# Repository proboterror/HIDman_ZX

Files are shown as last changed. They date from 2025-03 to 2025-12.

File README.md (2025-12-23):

# HIDman ZX
Адаптер USB и PS/2 клавиатур/мышей для ZX Spectrum.

## Входные требования:
- Разработать универсальный простой в повторении недорогой открытый интерфейс USB / PS/2 клавиатур и мышей.
- Должны поддерживаться как минимум два USB устройства одновременно
- Включает прошивку микроконтроллера, референсную минимальную схему включения и пример тестовой платы в KiCad
- Основной фокус на сопровождаемости прошивки микроконтроллера
- Выход интерфейса клавиатуры: сигналы матрицы переключателей A8-A15, D0-D4
- Выход интерфейсов Kempston Mouse и Kempston Joystick: сигналы DI0-DI7, стробы записи регистров MX, MY, MKEY, JOY

**Дополнительно:**
- Поддержка USB HID геймпадов как Kempston Joystick и для эмуляции кнопок клавиатуры
- Выход сигналов для управления кнопками эмулятора дисковода GOTEK по горячим кнопкам клавиатуры
- Выход сигналов управления Z80 по горячим кнопкам клавиатуры: BUSRQ (PAUSE), NMI(MAGIC), RESET

**Не входит в требования:**
- Реализация платы для ZX-BUS
- Реализация портов и регистров контроллеров ZX клавиатуры и Kempston Mouse
- Реализация защиты портов USB от статики / короткого замыкания / повышенного напряжения

## Реализация
В качестве основы проекта был взят проект [HIDman](https://github.com/rasteri/HIDman): USB HID to XT / AT / PS/2 / Serial converter : адаптер USB устройств в PS/2 keyboard/mouse device. От HIDman была взята реализация стека USB Host без модификаций.

Схема использует недорогие доступные чипы от [Nanjing Qinheng Microelectronics](https://www.wch-ic.com):
- 8-bit Enhanced USB MCU [CH559L](./doc/8-bit%20Enhanced%20USB%20MCU%20CH559%20Datasheet%201.6.pdf): расширенный Intel 8051 совместимый микроконтроллер с двумя аппаратными USB Host
- 8x16 Analog Switch Array Chip [CH446Q](./doc/8x16%20Analog%20Switch%20Array%20Chip%20CH446Q%20Datasheet%201D.pdf): матрица аналоговых ключей 8x16 с последовательным интерфейсом

В код добавлены:
- Реализация асинхронных интерфейсов PS/2 клавиатуры и мыши
- Реализация матрицы контактов 8x5 ZX Spectrum клавиатуры с раскладкой Xrust
- Интерфейс матрицы ключей CH446Q
- Интерфейс для контроллера Kempston Mouse (DI+MX/MY/MKEY)
- Интерфейс для контроллера Kempston Joystick (DI+JOY)
- Интерфейс управления Z80 (PAUSE/MAGIC/RESET) по клавишам F10/F11/F12
- Интерфейс управления кнопками GOTEK (RIGHT/LEFT/SELCT) по сочетанию клавиш CTRL+ RIGHT/LEFT/DOWN/UP

## Детали реализации

Тестовая плата для отладки присоединяется сверху к [ZX Spectrum Pentagon 128 2023/2024 Interface Board](https://github.com/proboterror/Pentagon_128_Interface_Board). Исходя из этого выбраны физические размеры и положение / распиновка разъема клавиатуры.

Интерфейс мыши расчитан на подсоединение к контроллеру, подобному [ZX_BUS_Mouse](https://github.com/proboterror/ZX_BUS_Mouse) с параллельной записью по шине 8-bit в регистры осей и колеса/кнопок. Колесо прокрутки мыши поддержано.

Исходный код поддержки PS/2 клавиатуры и интерфейса матрицы ZX Spectrum => CH446Q портирован из проекта расширенного интерфейса [ZX_RGBI2VGA-HDMI + GOTEK FlashFloppy I2C OSD + PS/2 Keyboard](https://github.com/proboterror/zx-rgbi-to-vga-hdmi_gotek-osd)

Исходный код поддержки PS/2 мыши портирован из экспериментальной ветки interrupt_processing_async проекта [ZX BUS Mouse](https://github.com/proboterror/ZX_BUS_Mouse/tree/interrupt_processing_async). Код обработки мыши по прерыванию clock в свою очередь основан на проекте Олега Трифонова [avr-mouse-ps2-to-serial](https://github.com/trol73/avr-mouse-ps2-to-serial). Код инициализации PS/2 мыши и основной цикл обработки событий асинхронный с минимальными задержками.

Тестирование показало, что MCU CH559L может работать от внутреннего генератора без использования внешнего кварцевого резонатора, выбор источника частоты из кода инициализации PLL.<br>
Конденсатор и резистор цепочки сброса MCU CH559L не нужны, т.к. есть внутренняя схема формирования сброса по питанию.

При тестировании проявился дефект: после подачи питания Gluk Reset Service всегда выводит экран Help, после нажатия Reset Z80 стартует нормально. Зажата клавиша 'A' ZX клавиатуры (адрес переключателя в матрице CH449Q 0x01) до момента программного зануления всех переключателей в CH449Q.<br>
В варианте с MCU RP2040 дефект не проявлялся.<br>
Расследование показало, что RP2040 при включении переводит (большинство) GPIO в режим input c pull-down (подтяжка к земле), выдавая логический '0' на GPIO pin. MCU CH559 при подаче питания активирует для портов pull-up резисторы (подтяжка к питанию 3.3V), выдавая логический '1' на выходы. Матрица переключателей CH446Q записывает значение сигнала DAT по адресу ранее выбранного переключателя при высоком уровне сигнала STB. Так как после аппаратного сброса CH446Q на входах STB и DAT был логический '1', то это приводило к нежелательной активации переключателя по адресу 0x01 (видимо в это значение сбрасывается внутренний регистр адреса).<br>
После подтяжки линии STB внешним резистором 10K к GND проблема почти решилась, но оставался нежелательный импульс длительностью 0.5 us в момент инициализации портов MCU. CH559 при сбросе инициализирует регистры P0..P3 выходного значения портов в значение 1111 1111b, и выстановка регистра P1 в 0x00 сразу после переключения порта P1 на выход приводила к такому эффекту. Исправлено выстановкой значения порта P1 до переключения его на выход.

## Режимы работы выходов
Входы / выходы матрицы клавиатуры A8-A15, D0-D4 и управляющих сигналов Z80 BUSRQ, NMI, RESET подключены к входам / выходам матрицы аналоговых ключей CH446Q. Общий вход X8 для сигналов Z80 BUSRQ, NMI, RESET подключен к GND.

Выходы кнопок GOTEK работают в режиме с открытым коллектором, при нажатии замыкают на GND.

Выход интерфейса Kempston Mouse и Kempston Joystick работает в режиме push-pull.

## Схема
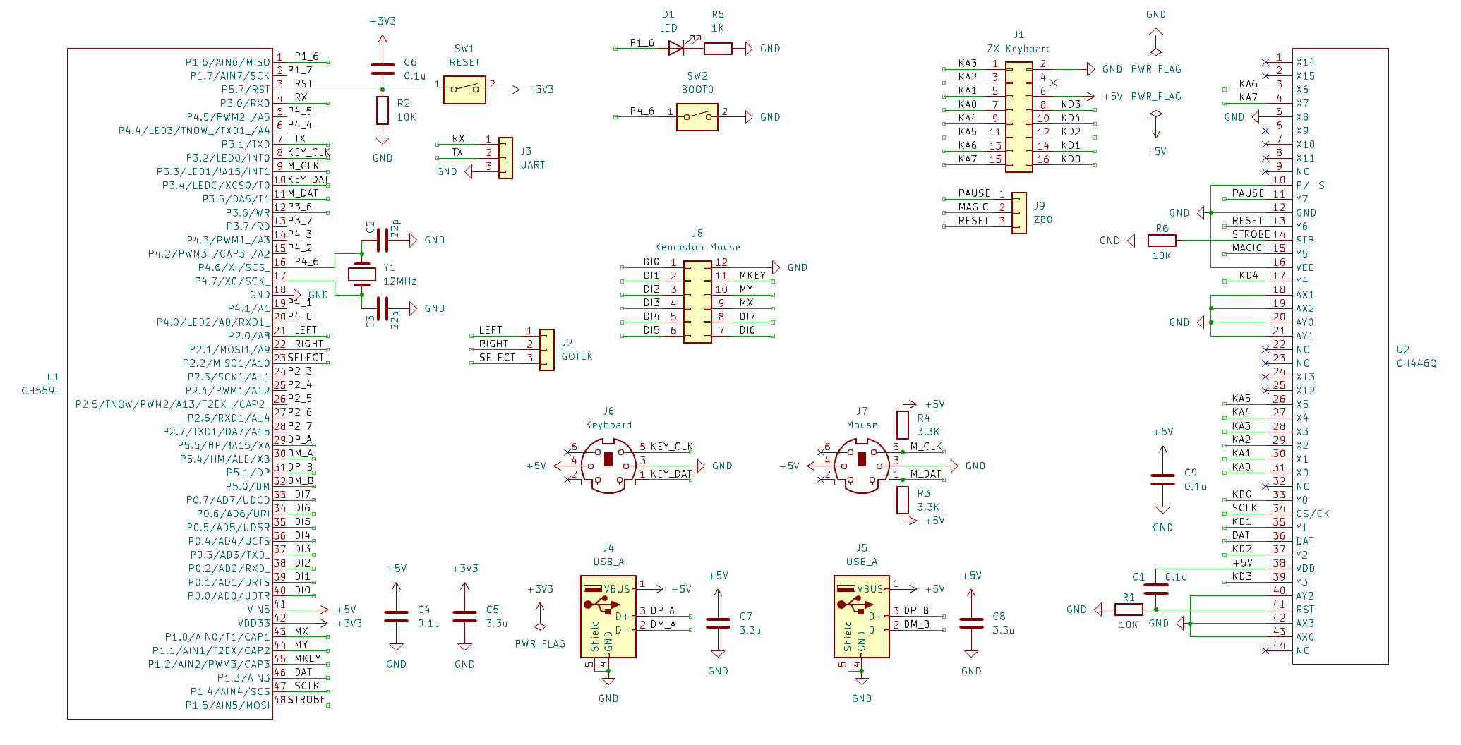
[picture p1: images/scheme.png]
scheme

## Тестовая плата
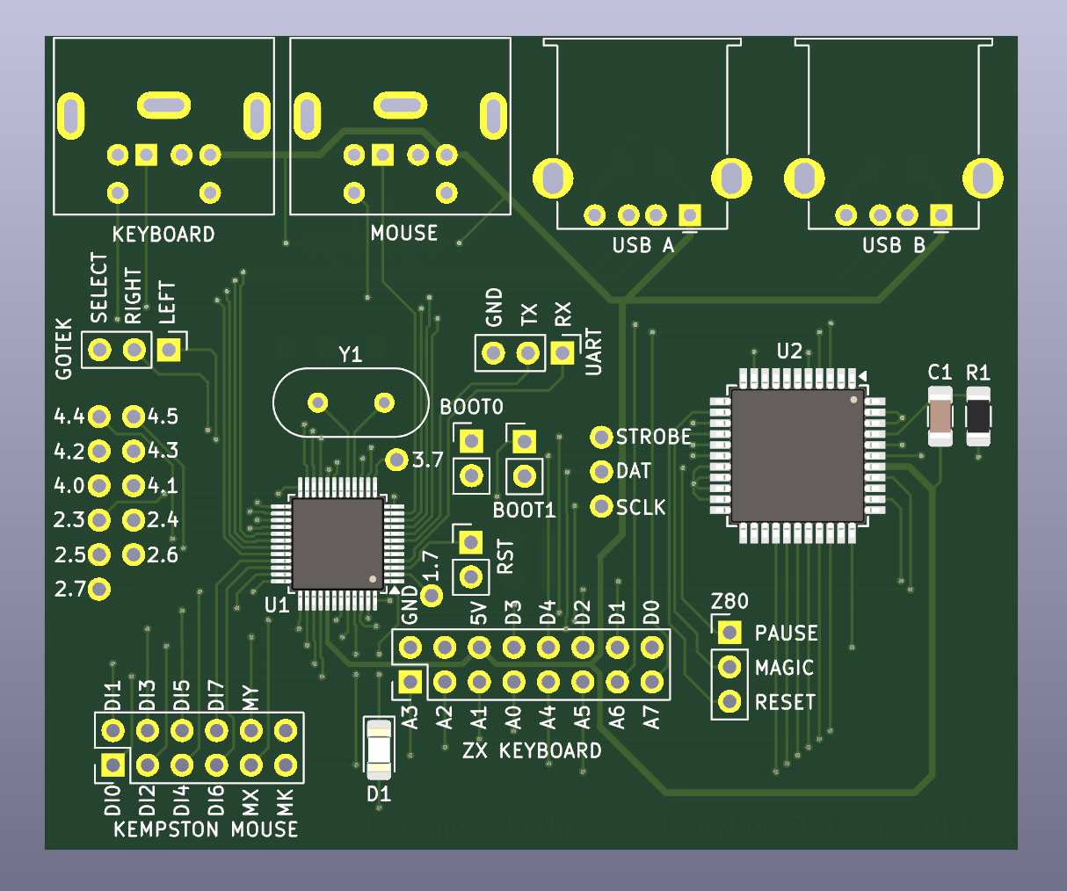
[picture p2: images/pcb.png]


## Текущий статус
- В firmware реализована поддержка PS/2 и USB мышей и клавиатур.
- Поддерживаются беспроводные мыши / клавиатуры Logitech c Unified Receiver и им подобные, работающие как стандартный USB HID.
- Реализована поддержка геймпадов/джойстиков, совместимых с USB HID, в том числе Sony DualShock 4, Sony PlayStation 5 DualSense.
- Реализованы специальные драйверы для геймпадов Sony DualShock 3, XBox 360 USB Controller, XBox One / Series S/X Controller.
- Реализована экспериментальная поддержка SEGA Mega Drive / Genesis геймпада как 3-кнопочного.
- Проверена работа выходных портов мыши / клавиатуры / джойстика / GOTEK / Z80.
- Поддержка USB хабов и конфигурация беспроводная клавиатура/мышь + gamepad не тестировались, но заявлены в оригинальном проекте.
- События от USB HID геймпадов транслируются в нажатия кнопок клавиатуры и Kempston Joystick.
- События от геймпадов с специальным драйвером транслируются в нажатия Kempston Joystick.

## Известные проблемы

## ToDo
- Код обработки событий от PS/2 клавиатуры не обрабатывает ошибки parity. После тестирования стабильности работы уточнить необходимость отправки устройству PS/2 команды RESEND / RESET и очистки буфера ввода.
- Добавить минимальный код трансляции нажатия кнопок геймпадов с специальным драйвером (PS3/XBox) в события клавиатуры.
<hr>

# Вариант для шины ZX-BUS (Nemo-BUS)
Для большей осмысленности существования прошивки MCU и востребованности реализована плата в формате ZX-BUS с полной поддержкой всех возможностей прошивки.

Плата реализует интерфейсы клавиатуры, Kempston Mouse и Kempston Joystick (8 bit), позволяет подключить как минимум 2 USB устройства и PS/2 клавиатуру / мышь.<br>
Интерфейс клавиатуры работает одновременно с портом клавиатуры / магнитофона на основной плате компьютера.

## Схема
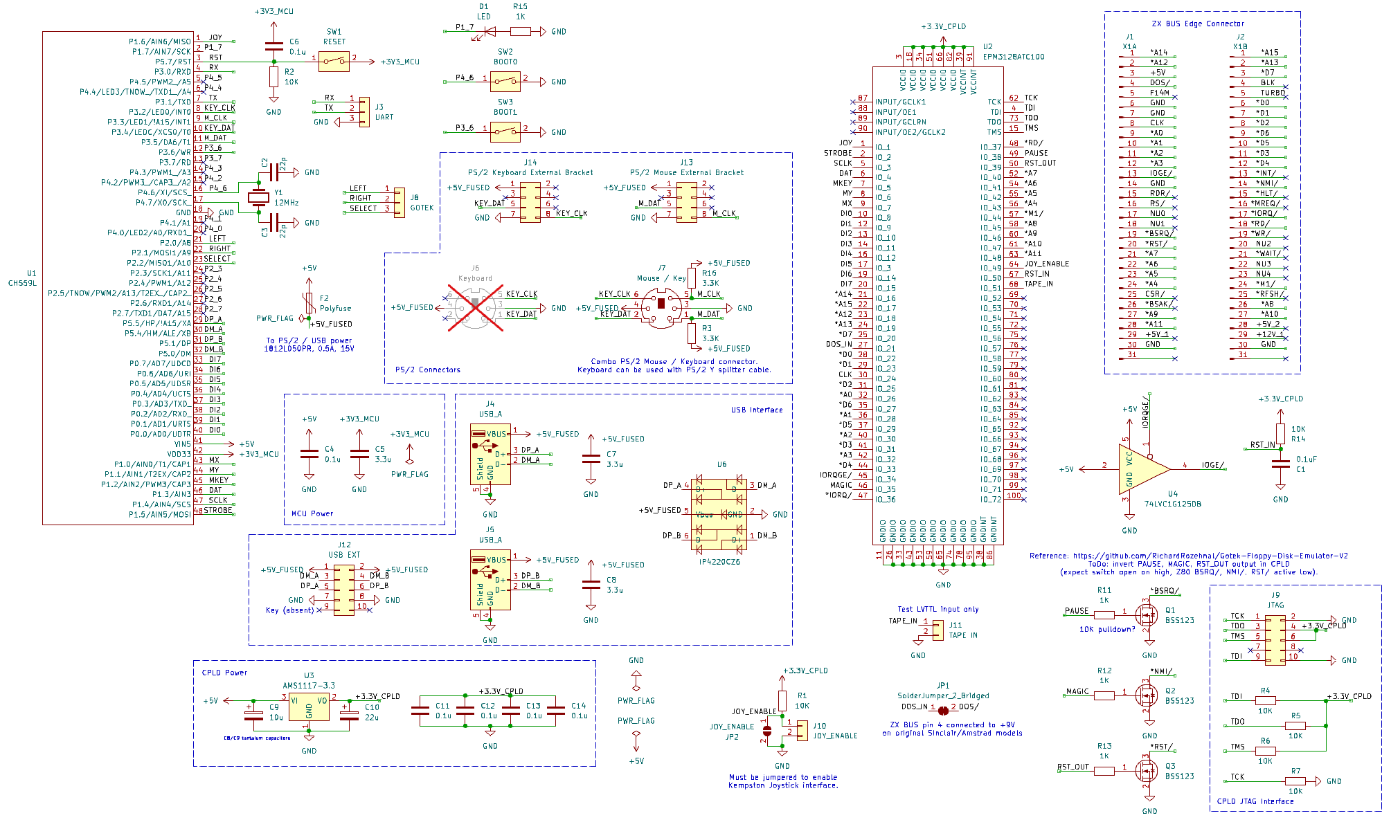
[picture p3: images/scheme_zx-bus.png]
scheme

## Плата
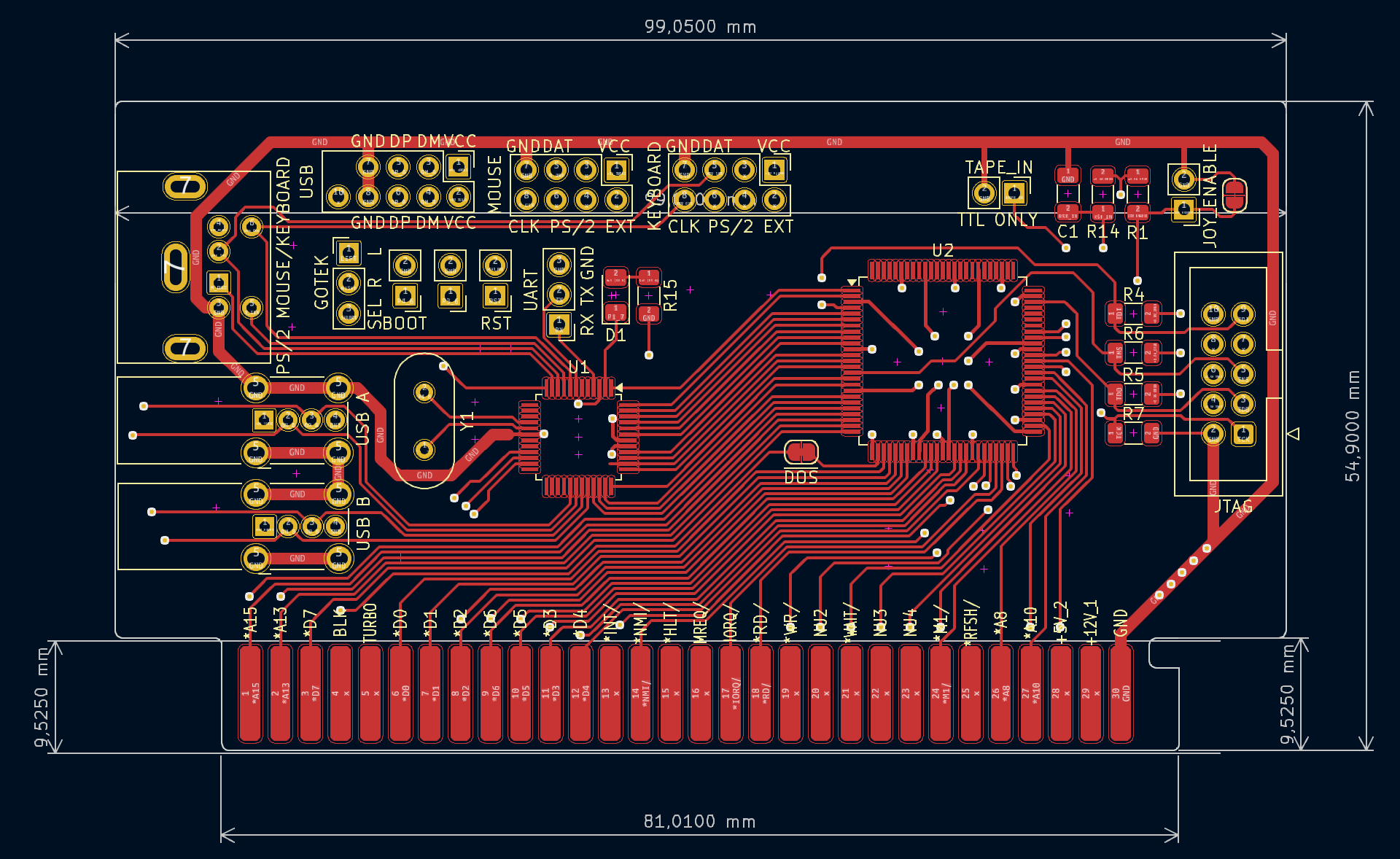
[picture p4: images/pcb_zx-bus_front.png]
front

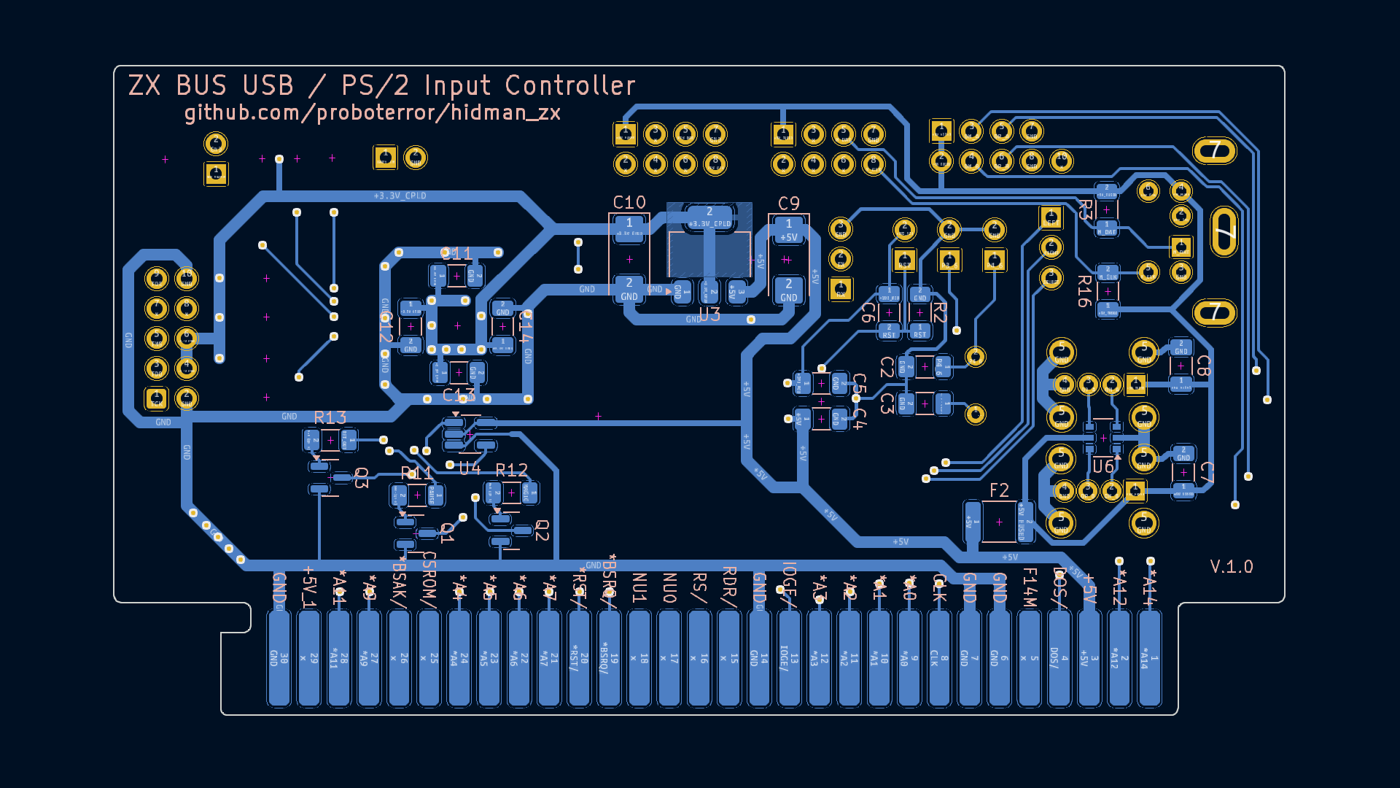
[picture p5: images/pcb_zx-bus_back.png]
back

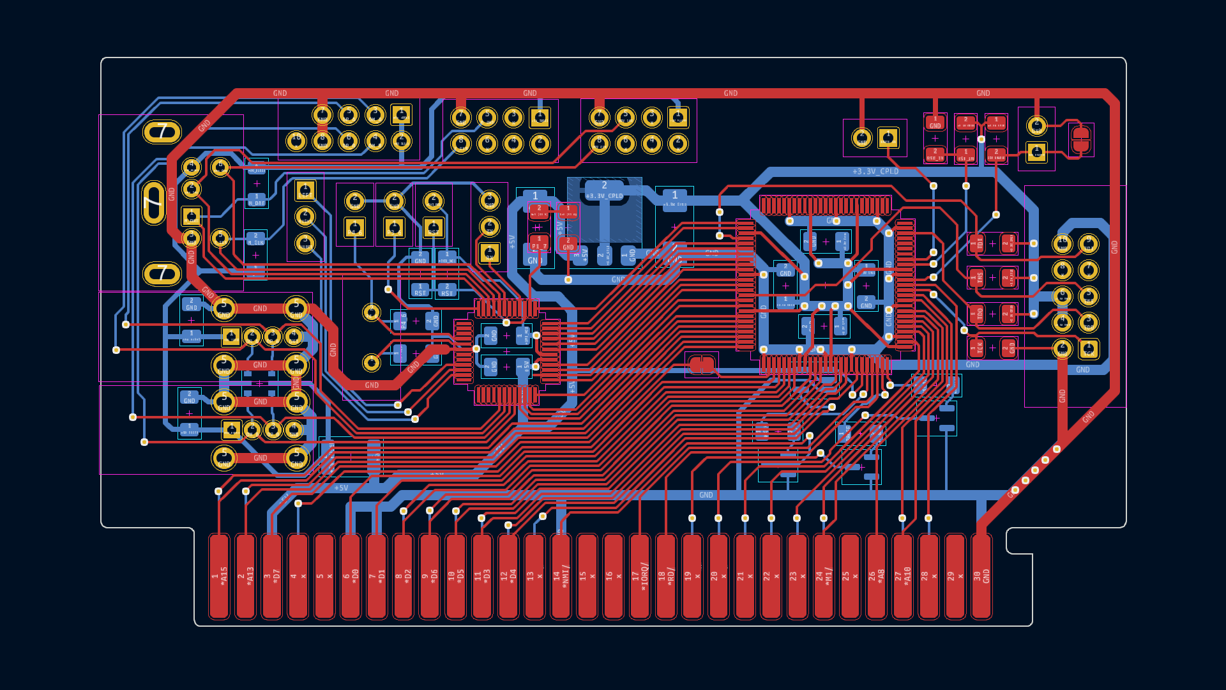
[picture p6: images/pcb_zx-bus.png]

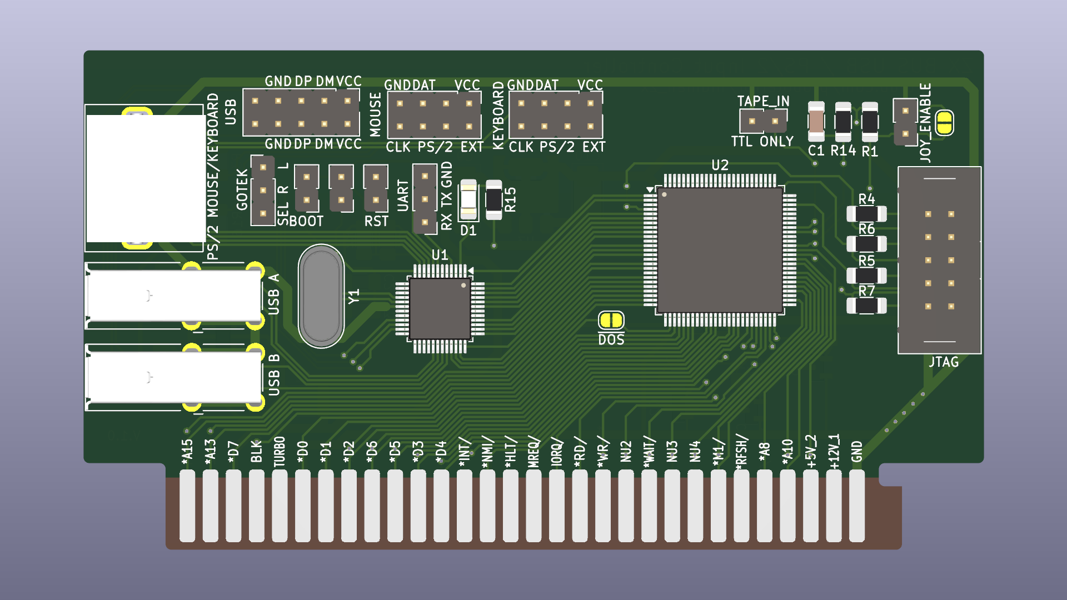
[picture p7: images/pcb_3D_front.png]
3D front

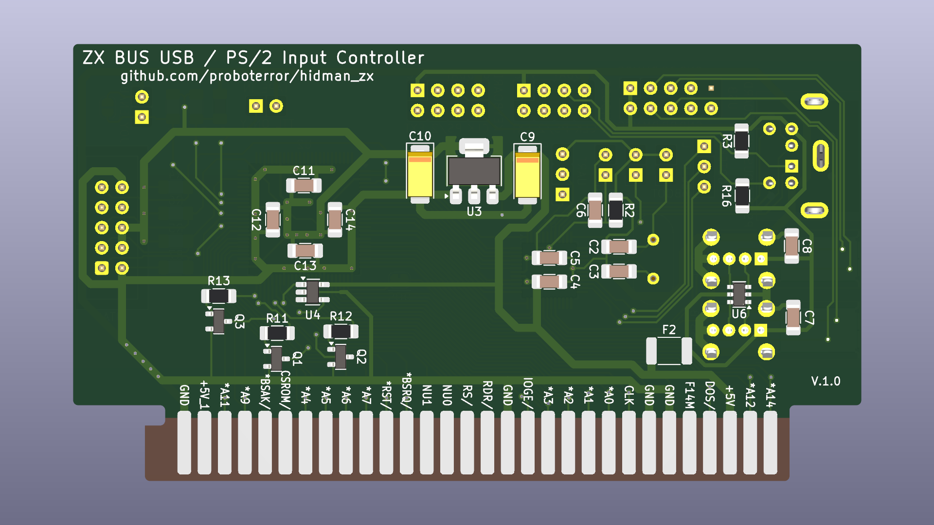
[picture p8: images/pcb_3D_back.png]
3D back

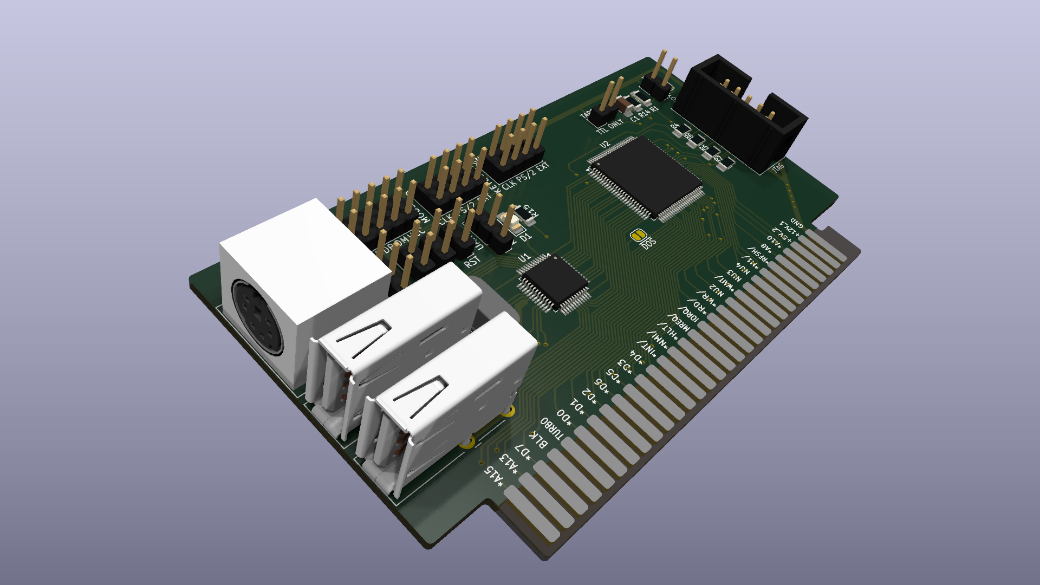
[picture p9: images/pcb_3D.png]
3D


## Выбор требований
- Плата должна содержать 2 порта USB и порты PS/2 мыши / клавиатуры, с возможностью подключения стандартных внешних планок.
- Использовать доступные и недорогие компоненты.
- Высота платы должна быть минимально возможной, максимальна ширина / высота 99 мм.
- Предусмотреть защиту портов от короткого замыкания (PS/2 / USB) и статического электричества (USB). Плата должна быть работоспособна без запаянных элементов защиты портов USB от статического электричества.
- Порт Kempston Joystick должен быть отключаемый по причине потенциальных конфликтов / не нужности.
- Штыревые разъемы не обязательны к запайке.
- SMD конденсаторы и резисторы форм фактора 1206 для удобства ручной сборки.

## Детали реализации
Матрица переключателей клавиатуры и специальных кнопок вместо отдельного чипа CH446Q помещена в CPLD вместе с дешифраторам адресов и регистрами интерфейсов, с сохранением последовательного интерфейса для доступа (drop-in replacement).

CPLD Altera EPM3128ATC100 выбрана исходя из доступности и минимальной необходимой емкости в макроячейках.<br>

Текущая реализация использует неполную дешифрацию портов клавиатуры, Kempston Mouse, Kempston Joystick.<br>
В идеале для Kempston Joystick желательна полная дешифрация нижних 8 бит адреса порта #1F, но для этого нужна нетривиальная оптимизация.<br>

Плата не блокирует встроенные порты клавиатуры и магнитофона для их параллельной работы.<br>
Плата полностью блокирует встроенный порт Kempston Joystick и порты Kempston Mouse; можно отредактировать описание для параллельной работы интерфейсов Kempston Joystick.<br>
Интерфейс клавиатуры для разделения шины данных подключается к шине в режиме с открытым коллектором.

Использовано порядка 107 из 128 макроячеек. Сложность описания и потребление элементарных компонентов (AND, OR, MUX, tri-state) в выходной RTL map требует особого внимания, при увеличении сложности fitter не может распределить ресурсы CPLD.<br>
Описание схемы в CPLD и testbench для тестирования написаны на языке System Verilog.

Интерфейс Kempston Joystick восьмибитный (4 направления + 4 кнопки) и по умолчанию отключен, включение через jumper / solder jumper.

Интерфейс мыши полный с поддержкой колеса мыши и трех кнопок.

Сигнал IORQGE/ буферизирован до уровня 5V через tri-state буфер 74LVC1G125DB.<br>
Сигналы PAUSE, MAGIC, RESET от CPLD буферизированы на сигналы шины Z80 BUSRQ/, NMI/, RST через FET транзисторные ключи BSS123.

Набор и форма разъемов выбраны исходя из минимальной высоты платы и потенциальной востребованности.<br>
По этой причине разъем PS/2 mini DIN 6 pin комбинированный: PS/2 мышь может быть подключена напрямую, для подключения PS/2 клавиатуры потребуется доступный недорогой Y splitter cable.

Разъемы USB компактные вертикальные [Würth Elektronik 614004134726](https://www.we-online.com/en/components/products/COM_TYPE_A_UP_RIGHT#614004134726) или их распространенные [аналоги](https://aliexpress.ru/item/1005003752018041.html?sku_id=12000028387034115).

Сигналы обоих портов USB и PS/2 мыши / клавиатуры также выведены на штыревые разъемы для подключения стандартных внешних планок/выбросов для двух портов USB или отдельных портов PS/2.

## Схема сброса CPLD
Важный момент, в многих реализациях игнорируемый.<br>
Для корректной работы ПО в ROM, исполняемого сразу после _включения_ компьютера, например Gluk Reset Service, требуется чтобы регистры матрицы клавиатуры и контроллера Kempston Mouse содержали корректные значения почти сразу после включения (порядка 24 ms): микроконтроллер интерфейса не успевает обновить их значения.<br>
Необходим внутрисхемный сброс регистров CPLD в нужное состояние по системному сигналу RESET _или_ самостоятельное формирование сигнала сброса при включении.<br>
Выбран второй вариант, т.к. CPLD также может формировать системный сигнал RESET (RST_OUT) исходя из значения внутреннего регистра, и это может вводить циклическую зависимость.

Сброс происходит по нисходящему фронту сигнала (более правильно было бы по уровню сигнала).

## Защита портов
Защита портов USB / PS/2 от короткого замыкания: самовосстанавливающийся предохранитель форм-фактора 1812 (Littelfuse 1812L050PR, 0.5A, 15V) (номинал требует уточнения, предельная нагрузка отдельного порта USB 0.5A@5V, возможно заменить на Bourns MF-NSMF075-2, 0.75 А, 6V, 1206).

Защита портов USB от статического электричества: [IP4220CZ6 Dual USB 2.0 ESD Protection TVS Array](doc/IP4220CZ6%20Dual%20USB%202.0%20integrated%20ESD%20protection%20[NXP].pdf). Может быть не установлена.<br>
В плате версии 1.0 подключена некорректно (?) и не должна устанавливаться.<br>
В плате версии 1.1 подключена в соответствии с datasheet, но блокирует порт USB для прошивки MCU.

## Зарезервированные сигналы
В CPLD заведены, но не используются сигналы шины ZX-BUS: CLK.<br>
Также заведен сигнал DOS/. Сигнал присутствует только на шине Nemo-BUS xUSSR клонов, в оригинальных моделях ZX-Spectrum с шиной ZX-BUS на этом контакте напряжение питания +9V. Чтобы обратить внимание на этот момент, сигнал подключен через замкнутый solder jumper.

## Порт Tape In
Порт входа магнитофона подключен к 6 биту порта #FE клавиатуры, соответственно при блокировке внутреннего порта клавитуры потенциально отключается и порт магнитофона.<br>
Для экспериментов на плате выведен разъем TAPE_IN. К порту можно подключить только LVTTL 3.3V сигнал, например от эмулятора магнитофона на TZXDuino.

## Текущий статус
- Прошивка CPLD проверена через testbench в ModelSim: опция "Tools/Run EDA Simulation Tool/EDA RTL Simulation" в Quartus. Должен быть установлен ModelSim из дистрибутива Quartus (использовалась версия 13.0sp1).
- Платы собраны и протестированы.
- Протестированы контроллеры Kempston Mouse, Kempston Joystick, ZX матричной клавиатуры: работают, корректно сбрасываются при включении. Реализация матрицы клавиатуры позволяет зажимать много кнопок без эффекта фантомных нажатий, в том числе при маппинге с HID геймпада.
- Клавиатура работает параллельно с портом клавиатуры и магнитофона на основной плате.
- Работа сигналов PAUSE, MAGIC, RESET через транзисторные ключи на шину проверена.
- Работа TTL входа TAPE_IN не проверена.
- ESD защита портов блокирует работу USB и не должна устанавливаться.

## Известные проблемы
- При включении в прошивке CPLD поддержки всех трех интерфейсов (Mouse, Joystick, Keyboard) (107 из 128 macrocells) интерфейс клавиатуры начинает работать нестабильно, в том числе при нажатии определенной кнопки джойстика.
Предположительно связано с неоптимальным распространением сигналов в комбинаторной схеме при большом заполнении CPLD.
В качестве временного решения закомментирована поддержка Kempston Joystick (94 из 128 macrocells).

## Сборка проекта
Для сборки прошивки из исходников потребуются: компилятор SDCC 3.9.3, GNU утилиты в составе msys2.
- Скопировать / установить [SDCC 3.9.3](https://github.com/atc1441/CH559sdccUSBHost/tree/master/SDCC). Добавить путь к SDCC/bin в переменную окружения PATH.
- Установить [MSYS2](https://www.msys2.org/). Путь к msys64/usr/bin должен быть в PATH.

Компиляция:
```
cd firmware
build-release.bat
```
Файлы прошивки сохраняются в каталоге firmware/out

## Прошивка CH559L
Необходимо установить [WCH ISP Studio](https://www.wch.cn/downloads/WCHISPTool_Setup_exe.html)
См. оригинальную инструкцию по прошивке ниже.

Потребуется кабель USB A - USB A (вилка - вилка).

Вход в режим програмирования:
- Запустить WCH ISP Studio, выбрать режим 
- Отсоединить контроллер от внешнего питания / устройств
- Замкнуть jumper BOOT0 (P4.6)
- Подключить контроллер через разъем USB_B к ПК
- Контроллер должен появиться в списке Dev list
- При неудаче повторить

Программирование:
- Выбрать файл прошивки
- Нажать Download
- При неудаче повторить

Примечания:
- Процедура прошивки может быть нестабильной / очень нестабильной в зависимости от контроллера USB в ПК.
- Вход в режим программирования через запуск bootloader'а прошивкой при сбросе (BOOT1 + RESET) не тестировался.
- Для CH559L заявлена поддержка serial programmer, есть опция в WCH ISP Studio и доступен инструмент [CH55x_python_flasher](https://github.com/hexeguitar/CH55x_python_flasher) для Windows / Linux, не тестировалось.

## Схожие проекты
[Контроллер для USB клавиатуры и мыши](https://zx-pk.ru/threads/34912-kontroller-dlya-usb-klaviatury-i-myshi.html)
[[github]](https://github.com/Igor-azx987sa/ZXKM)<br>
(С) Игорь Матвеев @azx987sa 2023<br>
Микроконтроллер ATmega328P, USB HOST controller CH9350, EPM7128<br>

[PentagonExpander](https://github.com/MikhaelKaa/pentagonexpander) (WiP)<br>
(С) Михаил Каа MikhaelKaa 2023<br>
USB / PS/2 мышь / клавиатура, Kempston Mouse / Joystick для Pentagon 128<br>
Микроконтроллер STM32, CPLD EPM7128

[USB2SPECTRUM](https://github.com/MikhaelKaa/usb2spectrum) (WiP)<br>
(С) Михаил Каа MikhaelKaa 2023-2024<br>
USB клавиатура / gamepad, PS/2 клавиатура, Kempston Joystick.<br>
Микроконтроллер STM32, CPLD EPM7064

[Периферийный контроллер для Скорпиона с поддержкой USB](https://zx-pk.ru/threads/34458-periferijnyj-kontroller-dlya-skorpiona-s-podderzhkoj-usb.html)
[[github]](https://github.com/psk7/scorpion-card-pub)<br>
(С) Kireev Sergey psk 2022<br>
Микроконтроллер ATmega328P, USB HOST controller MAX3421EEHJ, EPM3064

[usb_to_zx_spectrum](https://github.com/billgilbert7000/usb_to_zx_spectrum)<br>
(C) Constantin billgilbert7000 2024<br>
Универсальный контроллер USB клавиатуры для подключения к компьютерам ZX Spectrum.<br>
Микроконтроллер RP2040, матрица ключей MT8816

[ZX HID Keyboard Controller](https://zx-pk.ru/threads/24088-zx-hid-keyboard-controller.html)<br>
(C) Anykey 2014<br>
Микроконтроллер PIC24FJ64GB002, EPM7064

[PS/2 Universal Keyboard Controller](https://zx-pk.ru/threads/33211-universalnyj-kontroller-ps-2-klaviatury-dlya-kompyuterov-s-matrichnymi-klaviaturami.html)<br>
(C) Xrust 2021<br>
Микроконтроллер ATmega328P, матрица ключей MT8816

[Вариация безвейтового контроллера PS/2 клавиатуры для Spectrum - компактный вариант](https://zx-pk.ru/threads/35030-variatsiya-bezvejtovogo-kontrollera-ps-2-klaviatury-dlya-spectrum-kompaktnyj-variant.html)<br>
(C) Rio444 2023<br>
Микроконтроллер ATTiny25, EPM3064

[Контроллер клавиатуры PS/2 => ZX Spectrum для ZX_RGBI2VGA-HDMI](https://t.me/rgb2vga_hdmi)<br>
(C) Алекс Екб @Alex_Eburg 2024<br>
Микроконтроллер RP2040, матрица ключей CH446Q

<hr>

## USB HID to XT / AT / PS/2 / Serial converter

HIDman is an open source device to allow the use of modern USB keyboards and mice on legacy PCs.

# Features

* (should) Support the majority of standard USB keyboards and mice, including ones that use wireless dongles.
* Also supports (some) USB Game controllers - buttons/axes are mapped to keypresses or mouse actions

# Quickstart Guide

## USB Connection

You can connect many different combinations of USB devices to HIDman.

The most obvious being to connect a keyboard to one USB port, and a mouse to the other one :



Or, you could perhaps connect a wireless keyboard+mouse dongle to one port, and a game controller to the other :



Hub support can be hit-and-miss. This is (mostly) not HIDman's fault - many modern hubs don't support low-speed USB devices properly.

# Firmware Update

Firmware development is continuing, so if you have problems it's always worth updating to the latest version.

If you're on windows, first install WCH's ISP tool - https://www.wch.cn/downloads/WCHISPTool_Setup_exe.html
If on Mac or Linux, install ch55xtool : https://github.com/MarsTechHAN/ch552tool

The next step is to put the HIDman in firmware update mode.

1. Disconnect everything from HIDman, including all USB devices and PCs. (failure to do this may result in damage to HIDman, your PC, or both).
2. Hold down HIDman's ⏻ power button.
3. Use a USB A-to-A cable to connect HIDman's LOWER USB port to a USB port on your modern PC.

After that, update instructions will depend on your operating system.

## Windows

Follow the instructions in this diagram :



## Linux or Mac

Pass the -f parameter to ch55xtool specify the firmware file to load. For example :

```
python3 ch55xtool.py -f hidman_axp_v1.1.bin
```

## Technical description

The HIDman is based around the CH559 from WCH, a remarkably flexible chip with **two** USB HOST ports. This makes it ideal for our purposes.

The code is forked from atc1441's excellent repository - https://github.com/atc1441/CH559sdccUSBHost

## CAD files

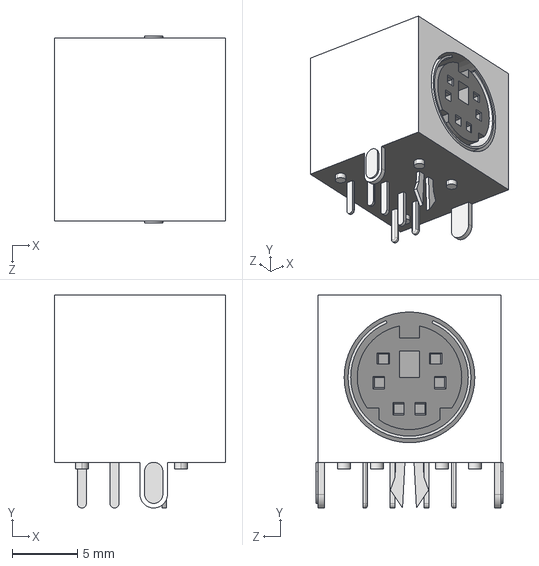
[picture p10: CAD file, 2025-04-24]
hardware/zx_bus/MINI-DIN-6.stp
13.1 x 16.3 x 14.3 mm

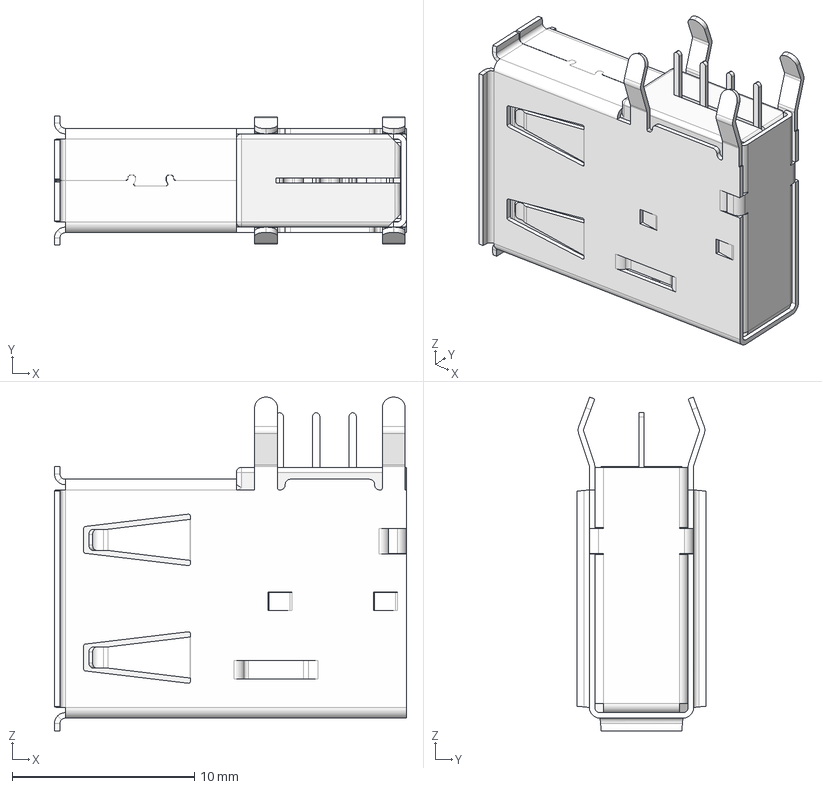
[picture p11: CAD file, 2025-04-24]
hardware/zx_bus/WR-COM USB 2.0 Up Right 614004134726 (rev1).stp
19.3 x 7.10 x 18.3 mm
Blech
Blech_Deckel
Pin_4
Gehäuse_Pin
Pin_3
Pin_2
Pin_1

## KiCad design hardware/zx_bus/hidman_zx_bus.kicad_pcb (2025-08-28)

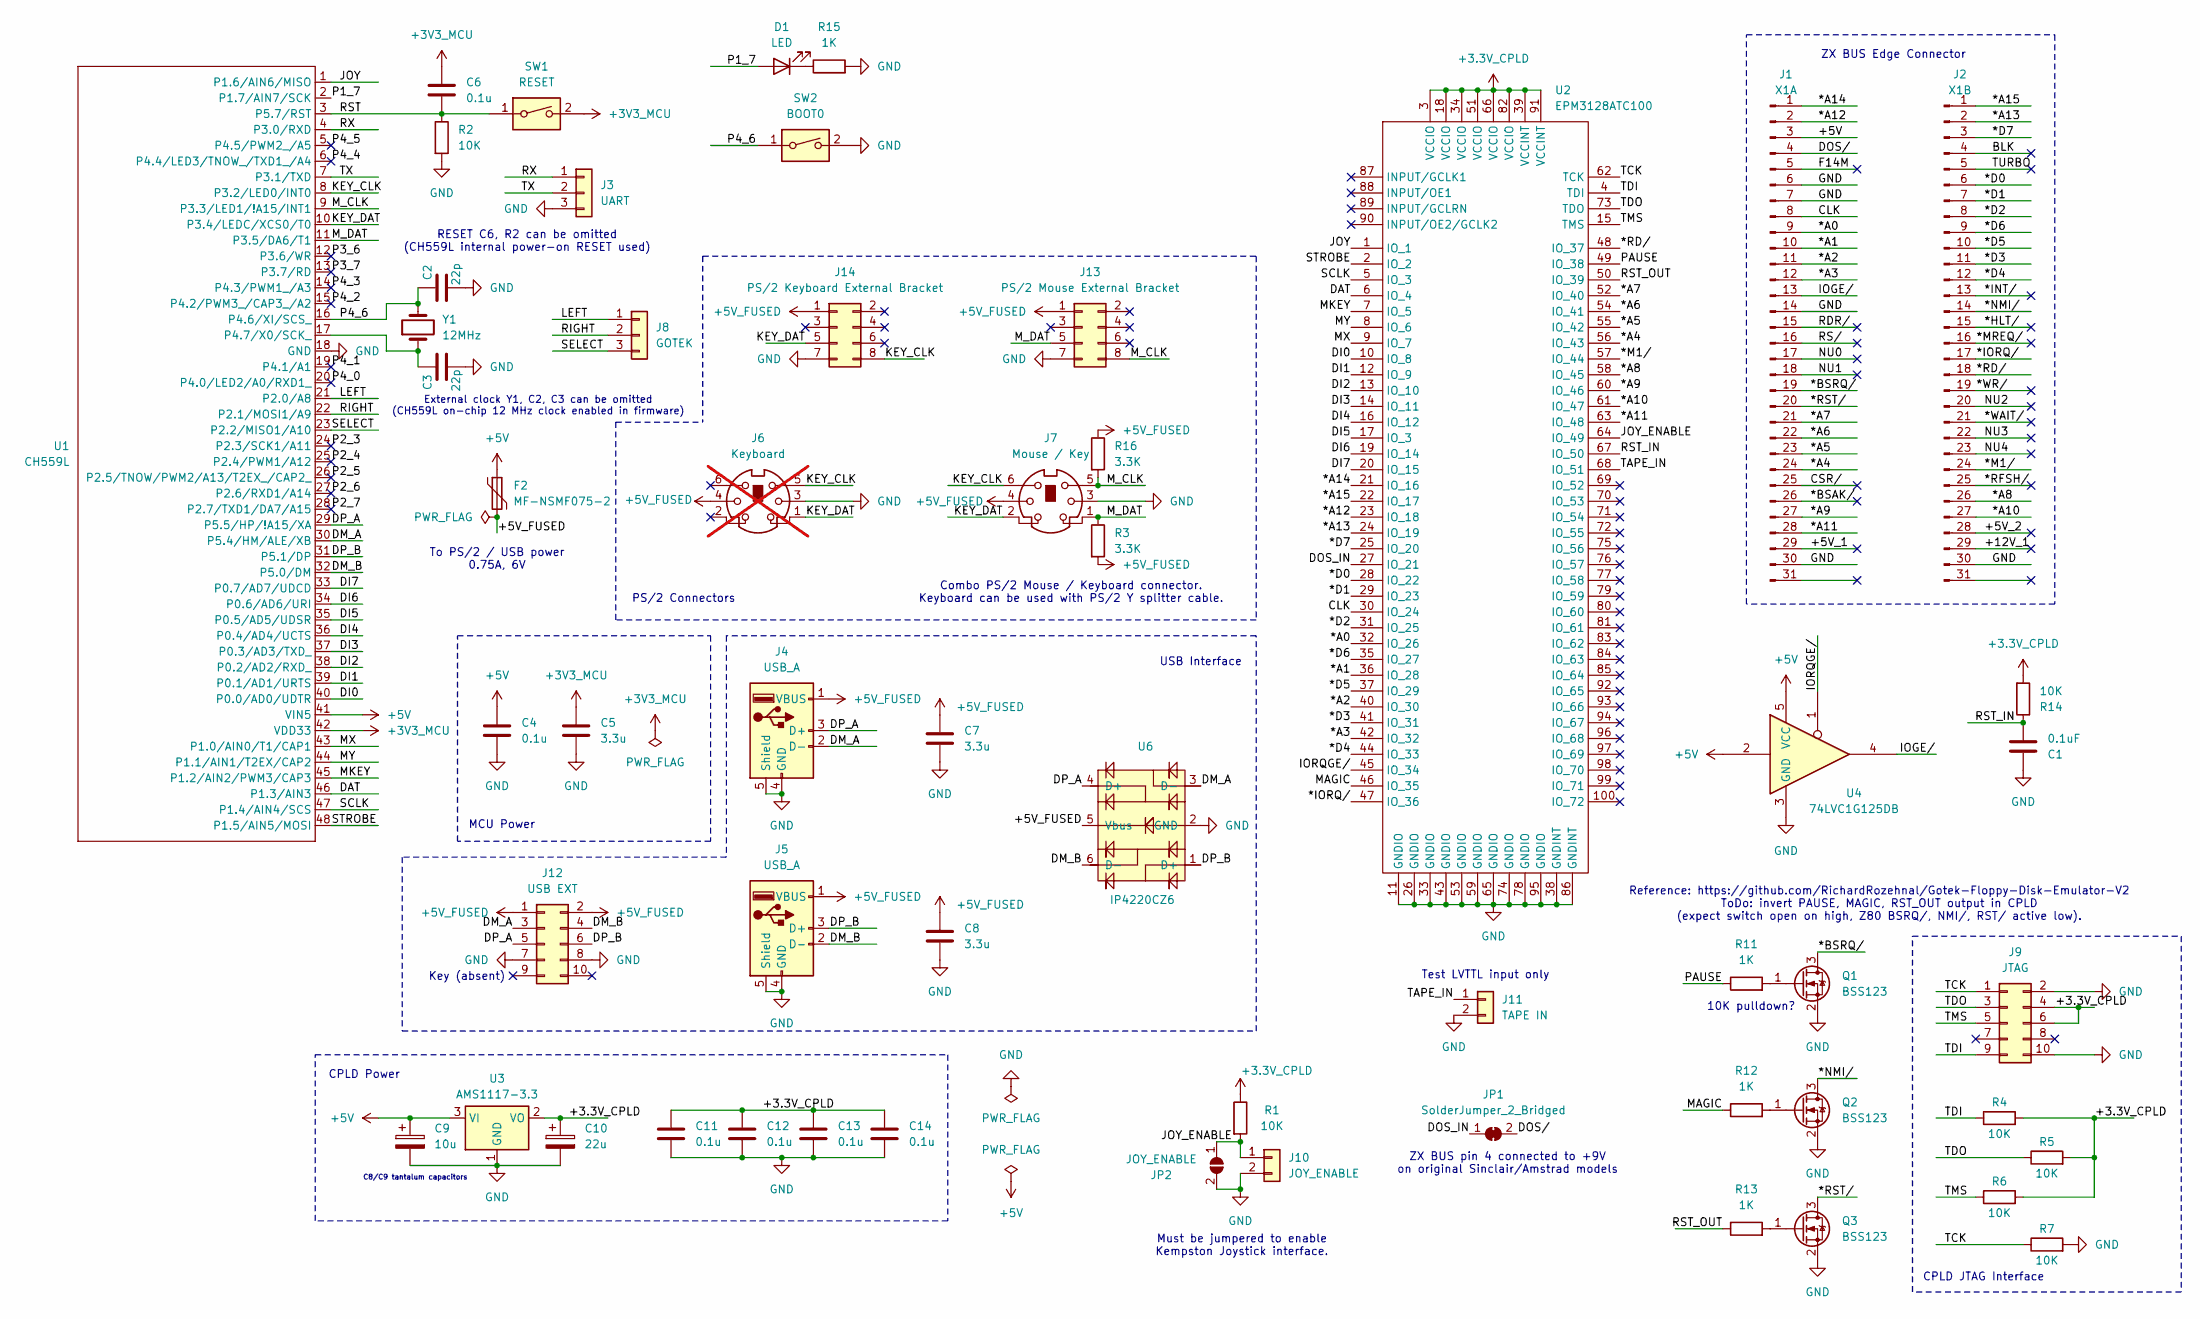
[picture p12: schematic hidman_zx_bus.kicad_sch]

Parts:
C1: 0.1uF; C_1206_3216Metric_Pad1.33x1.80mm_HandSolder
C2, C3: 22p; C_1206_3216Metric_Pad1.33x1.80mm_HandSolder
C4, C6, C11, C12, C13, C14: 0.1u; C_1206_3216Metric_Pad1.33x1.80mm_HandSolder
C5, C7, C8: 3.3u; C_1206_3216Metric_Pad1.33x1.80mm_HandSolder
C9: 10u; CP_EIA-6032-28_Kemet-C_Pad2.25x2.35mm_HandSolder
C10: 22u; CP_EIA-6032-28_Kemet-C_Pad2.25x2.35mm_HandSolder
D1: LED; LED_1206_3216Metric_Pad1.42x1.75mm_HandSolder
F2: MF-NSMF075-2; Fuse_1206_3216Metric_Pad1.42x1.75mm_HandSolder
J1: X1A; PinSocket_1x31_P2.54mm_2
J2: X1B; PinSocket_1x31_P2.54mm_2
J3: UART; PinHeader_1x03_P2.54mm_Vertical
J4, J5: USB_A; USB_A_Wuerth_614004134726_Horizontal
J6: Keyboard; Connector_Mini-DIN_Female_6Pin_2rows; not fitted
J7: Mouse / Key; Connector_Mini-DIN_Female_6Pin_2rows
J8: GOTEK; PinHeader_1x03_P2.54mm_Vertical
J9: JTAG; IDC-Header_2x05_P2.54mm_Vertical
J10: JOY_ENABLE; PinHeader_1x02_P2.54mm_Vertical
J11: TAPE IN; PinHeader_1x02_P2.54mm_Vertical
J12: USB EXT; PinHeader_2x05_P2.54mm_Vertical
J13: PS/2 Mouse External Bracket; PinHeader_2x04_P2.54mm_Vertical
J14: PS/2 Keyboard External Bracket; PinHeader_2x04_P2.54mm_Vertical
JP1: SolderJumper_2_Bridged; SolderJumper-2_P1.3mm_Bridged_RoundedPad1.0x1.5mm
JP2: JOY_ENABLE; SolderJumper-2_P1.3mm_Open_RoundedPad1.0x1.5mm
Q1, Q2, Q3: BSS123; SOT-23
R1, R2, R4, R5, R6, R7, R14: 10K; R_1206_3216Metric_Pad1.30x1.75mm_HandSolder
R3, R16: 3.3K; R_1206_3216Metric_Pad1.30x1.75mm_HandSolder
R11, R12, R13, R15: 1K; R_1206_3216Metric_Pad1.30x1.75mm_HandSolder
SW1: RESET; PinHeader_1x02_P2.54mm_Vertical
SW2: BOOT0; PinHeader_1x02_P2.54mm_Vertical
U1: CH559L; LQFP-48_7x7mm_P0.5mm
U2: EPM3128ATC100; TQFP-100_14x14mm_P0.5mm
U3: AMS1117-3.3; SOT-223-3_TabPin2
U4: 74LVC1G125DB; SOT-23-5_HandSoldering
U6: IP4220CZ6; TSOP-6_1.65x3.05mm_P0.95mm
Y1: 12MHz; Crystal_HC49-4H_Vertical

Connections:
+3.3V_CPLD: C10.1, C11.1, C12.1, C13.1, C14.1, J9.4, J9.6, R1.1, R4.2, R5.2, R6.2, R14.2, U2.3 (VCCIO), U2.18 (VCCIO), U2.34 (VCCIO), U2.39 (VCCINT), U2.51 (VCCIO), U2.66 (VCCIO), U2.82 (VCCIO), U2.91 (VCCINT), U3.2 (VO)
+3V3_MCU: C5.1, C6.1, SW1.2, U1.42 (VDD33)
+5V: C4.1, C9.1, F2.1, J1.3, U1.41 (VIN5), U3.3 (VI), U4.2, U4.5 (VCC)
+5V_FUSED: C7.1, C8.1, F2.2, J4.1 (VBUS), J5.1 (VBUS), J6.4, J7.4, J12.1, J12.2, J13.1, J14.1, R3.2, R16.1, U6.5 (Vbus)
/*A0: J1.9, U2.32 (IO_26)
/*A1: J1.10, U2.36 (IO_28)
/*A2: J1.11, U2.40 (IO_30)
/*A3: J1.12, U2.42 (IO_32)
/*A4: J1.24, U2.56 (IO_43)
/*A5: J1.23, U2.55 (IO_42)
/*A6: J1.22, U2.54 (IO_41)
/*A7: J1.21, U2.52 (IO_40)
/*A8: J2.26, U2.58 (IO_45)
/*A9: J1.27, U2.60 (IO_46)
/*A10: J2.27, U2.61 (IO_47)
/*A11: J1.28, U2.63 (IO_48)
/*A12: J1.2, U2.23 (IO_18)
/*A13: J2.2, U2.24 (IO_19)
/*A14: J1.1, U2.21 (IO_16)
/*A15: J2.1, U2.22 (IO_17)
/*BSAK/: J1.26
/*BSRQ/: J1.19, Q1.3 (D)
/*D0: J2.6, U2.28 (IO_22)
/*D1: J2.7, U2.29 (IO_23)
/*D2: J2.8, U2.31 (IO_25)
/*D3: J2.11, U2.41 (IO_31)
/*D4: J2.12, U2.44 (IO_33)
/*D5: J2.10, U2.37 (IO_29)
/*D6: J2.9, U2.35 (IO_27)
/*D7: J2.3, U2.25 (IO_20)
/*HLT/: J2.15
/*INT/: J2.13
/*IORQ/: J2.17, U2.47 (IO_36)
/*M1/: J2.24, U2.57 (IO_44)
/*MREQ/: J2.16
/*NMI/: J2.14, Q2.3 (D)
/*RD/: J2.18, U2.48 (IO_37)
/*RFSH/: J2.25
/*RST/: J1.20, Q3.3 (D)
/*WAIT/: J2.21
/*WR/: J2.19
/+5V_1: J1.29
/+5V_2: J2.28
/+12V_1: J2.29
/BLK: J2.4
/CLK: J1.8, U2.30 (IO_24)
/CSR/: J1.25
/DAT: U1.46 (P1.3/AIN3), U2.6 (IO_4)
/DI0: U1.40 (P0.0/AD0/UDTR), U2.10 (IO_8)
/DI1: U1.39 (P0.1/AD1/URTS), U2.12 (IO_9)
/DI2: U1.38 (P0.2/AD2/RXD_), U2.13 (IO_10)
/DI3: U1.37 (P0.3/AD3/TXD_), U2.14 (IO_11)
/DI4: U1.36 (P0.4/AD4/UCTS), U2.16 (IO_12)
/DI5: U1.35 (P0.5/AD5/UDSR), U2.17 (IO_3)
/DI6: U1.34 (P0.6/AD6/URI), U2.19 (IO_14)
/DI7: U1.33 (P0.7/AD7/UDCD), U2.20 (IO_15)
/DM_A: J4.2 (D-), J12.3, U1.30 (P5.4/HM/ALE/XB), U6.3 (D-)
/DM_B: J5.2 (D-), J12.4, U1.32 (P5.0/DM), U6.6 (D-)
/DOS_IN: JP1.1 (A), U2.27 (IO_21)
/DOS/: J1.4, JP1.2 (B)
/DP_A: J4.3 (D+), J12.5, U1.29 (P5.5/HP/!A15/XA), U6.4 (D+)
/DP_B: J5.3 (D+), J12.6, U1.31 (P5.1/DP), U6.1 (D+)
/F14M: J1.5
/IOGE/: J1.13, U4.4
/IORQGE/: U2.45 (IO_34), U4.1
/JOY: U1.1 (P1.6/AIN6/MISO), U2.1 (IO_1)
/JOY_ENABLE: J10.1, JP2.1 (A), R1.2, U2.64 (IO_49)
/KEY_CLK: J6.5, J7.6, J14.8, U1.8 (P3.2/LED0/INT0)
/KEY_DAT: J6.1, J7.2, J14.5, U1.10 (P3.4/LEDC/XCS0/T0)
/LEFT: J8.1, U1.21 (P2.0/A8)
/MAGIC: R12.1, U2.46 (IO_35)
/MKEY: U1.45 (P1.2/AIN2/PWM3/CAP3), U2.7 (IO_5)
/MX: U1.43 (P1.0/AIN0/T1/CAP1), U2.9 (IO_7)
/MY: U1.44 (P1.1/AIN1/T2EX/CAP2), U2.8 (IO_6)
/M_CLK: J7.5, J13.8, R16.2, U1.9 (P3.3/LED1/!A15/INT1)
/M_DAT: J7.1, J13.5, R3.1, U1.11 (P3.5/DA6/T1)
/NU0: J1.17
/NU1: J1.18
/NU2: J2.20
/NU3: J2.22
/NU4: J2.23
/P1_7: D1.2 (A), U1.2 (P1.7/AIN7/SCK)
/P2_3: U1.24 (P2.3/SCK1/A11)
/P2_4: U1.25 (P2.4/PWM1/A12)
/P2_5: U1.26 (P2.5/TNOW/PWM2/A13/T2EX_/CAP2_)
/P2_6: U1.27 (P2.6/RXD1/A14)
/P2_7: U1.28 (P2.7/TXD1/DA7/A15)
/P3_6: U1.12 (P3.6/WR)
/P3_7: U1.13 (P3.7/RD)
/P4_0: U1.20 (P4.0/LED2/A0/RXD1_)
/P4_1: U1.19 (P4.1/A1)
/P4_2: U1.15 (P4.2/PWM3_/CAP3_/A2)
/P4_3: U1.14 (P4.3/PWM1_/A3)
/P4_4: U1.6 (P4.4/LED3/TNOW_/TXD1_/A4)
/P4_5: U1.5 (P4.5/PWM2_/A5)
/P4_6: C2.1, SW2.1, U1.16 (P4.6/XI/SCS_), Y1.2
/PAUSE: R11.1, U2.49 (IO_38)
/RDR/: J1.15
/RIGHT: J8.2, U1.22 (P2.1/MOSI1/A9)
/RST: C6.2, R2.1, SW1.1, U1.3 (P5.7/RST)
/RST_IN: C1.2, R14.1, U2.67 (IO_50)
/RST_OUT: R13.1, U2.50 (IO_39)
/RS/: J1.16
/RX: J3.1, U1.4 (P3.0/RXD)
/SCLK: U1.47 (P1.4/AIN4/SCS), U2.5 (IO_3)
/SELECT: J8.3, U1.23 (P2.2/MISO1/A10)
/STROBE: U1.48 (P1.5/AIN5/MOSI), U2.2 (IO_2)
/TAPE_IN: J11.1, U2.68 (IO_51)
/TCK: J9.1, R7.1, U2.62 (TCK)
/TDI: J9.9, R4.1, U2.4 (TDI)
/TDO: J9.3, R5.1, U2.73 (TDO)
/TMS: J9.5, R6.1, U2.15 (TMS)
/TURBO: J2.5
/TX: J3.2, U1.7 (P3.1/TXD)
GND: C1.1, C2.2, C3.2, C4.2, C5.2, C7.2, C8.2, C9.2, C10.2, C11.2, C12.2, C13.2, C14.2, J1.6, J1.7, J1.14, J1.30, J2.30, J3.3, J4.4 (GND), J4.5 (Shield), J5.4 (GND), J5.5 (Shield), J6.3, J7.3, J9.2, J9.10, J10.2, J11.2, J12.7, J12.8, J13.7, J14.7, JP2.2 (B), Q1.2 (S), Q2.2 (S), Q3.2 (S), R2.2, R7.2, R15.2, SW2.2, U1.18 (GND), U2.11 (GNDIO), U2.26 (GNDIO), U2.33 (GNDIO), U2.38 (GNDINT), U2.43 (GNDIO), U2.53 (GNDIO), U2.59 (GNDIO), U2.65 (GNDIO), U2.74 (GNDIO), U2.78 (GNDIO), U2.86 (GNDINT), U2.95 (GNDIO), U3.1 (GND), U4.3 (GND), U6.2 (GND)
unnamed: D1.1 (K), R15.1
unnamed: Q1.1 (G), R11.2
unnamed: Q2.1 (G), R12.2
unnamed: Q3.1 (G), R13.2
unnamed: C3.1, U1.17 (P4.7/X0/SCK_), Y1.1

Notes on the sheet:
ZX BUS Edge Connector
CPLD Power
Must be jumpered to enable Kempston Joystick interface.
External clock Y1, C2, C3 can be omitted (CH559L on-chip 12 MHz clock enabled in firmware)
USB Interface
Key (absent)
Reference: https://github.com/RichardRozehnal/Gotek-Floppy-Disk-Emulator-V2 ToDo: invert PAUSE, MAGIC, RST_OUT output in CPLD (expect switch open on high, Z80 BSRQ/, NMI/, RST/ active low).
MCU Power
RESET C6, R2 can be omitted (CH559L internal power-on RESET used)
CPLD JTAG Interface
ZX BUS pin 4 connected to +9V on original Sinclair/Amstrad models
Combo PS/2 Mouse / Keyboard connector. Keyboard can be used with PS/2 Y splitter cable.
Test LVTTL input only
PS/2 Connectors
To PS/2 / USB power 0.75A, 6V
10K pulldown?
C8/C9 tantalum capacitors

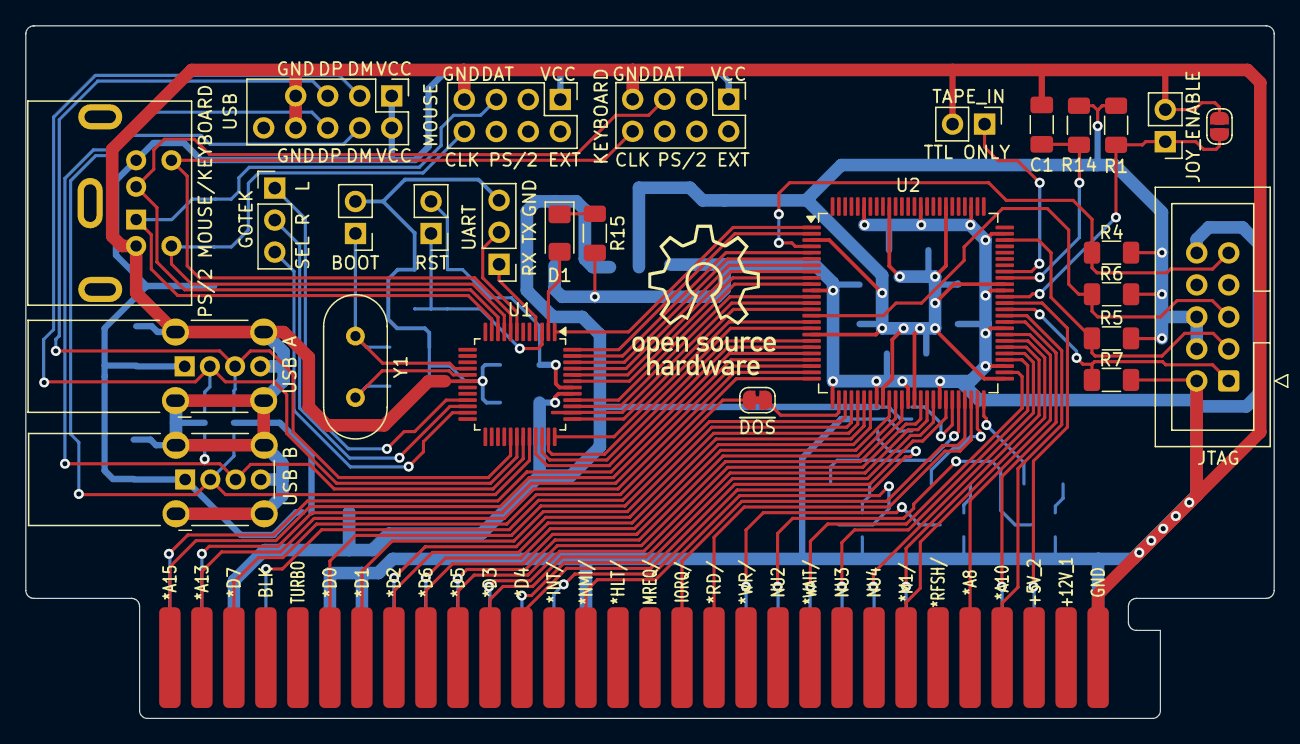
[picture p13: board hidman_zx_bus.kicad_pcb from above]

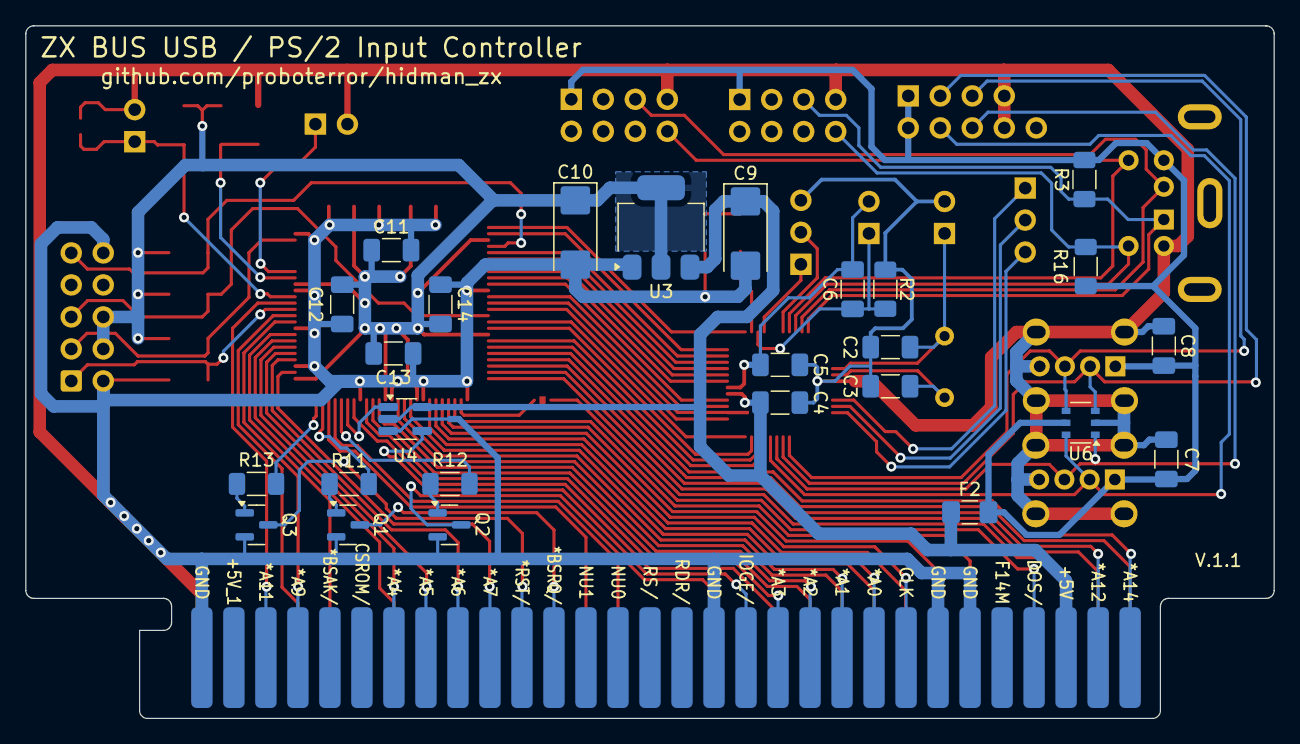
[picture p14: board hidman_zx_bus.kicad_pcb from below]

Board: 2 copper layers, 99.1 x 55.0 mm, 55 parts (27 on the bottom side), 86 nets.

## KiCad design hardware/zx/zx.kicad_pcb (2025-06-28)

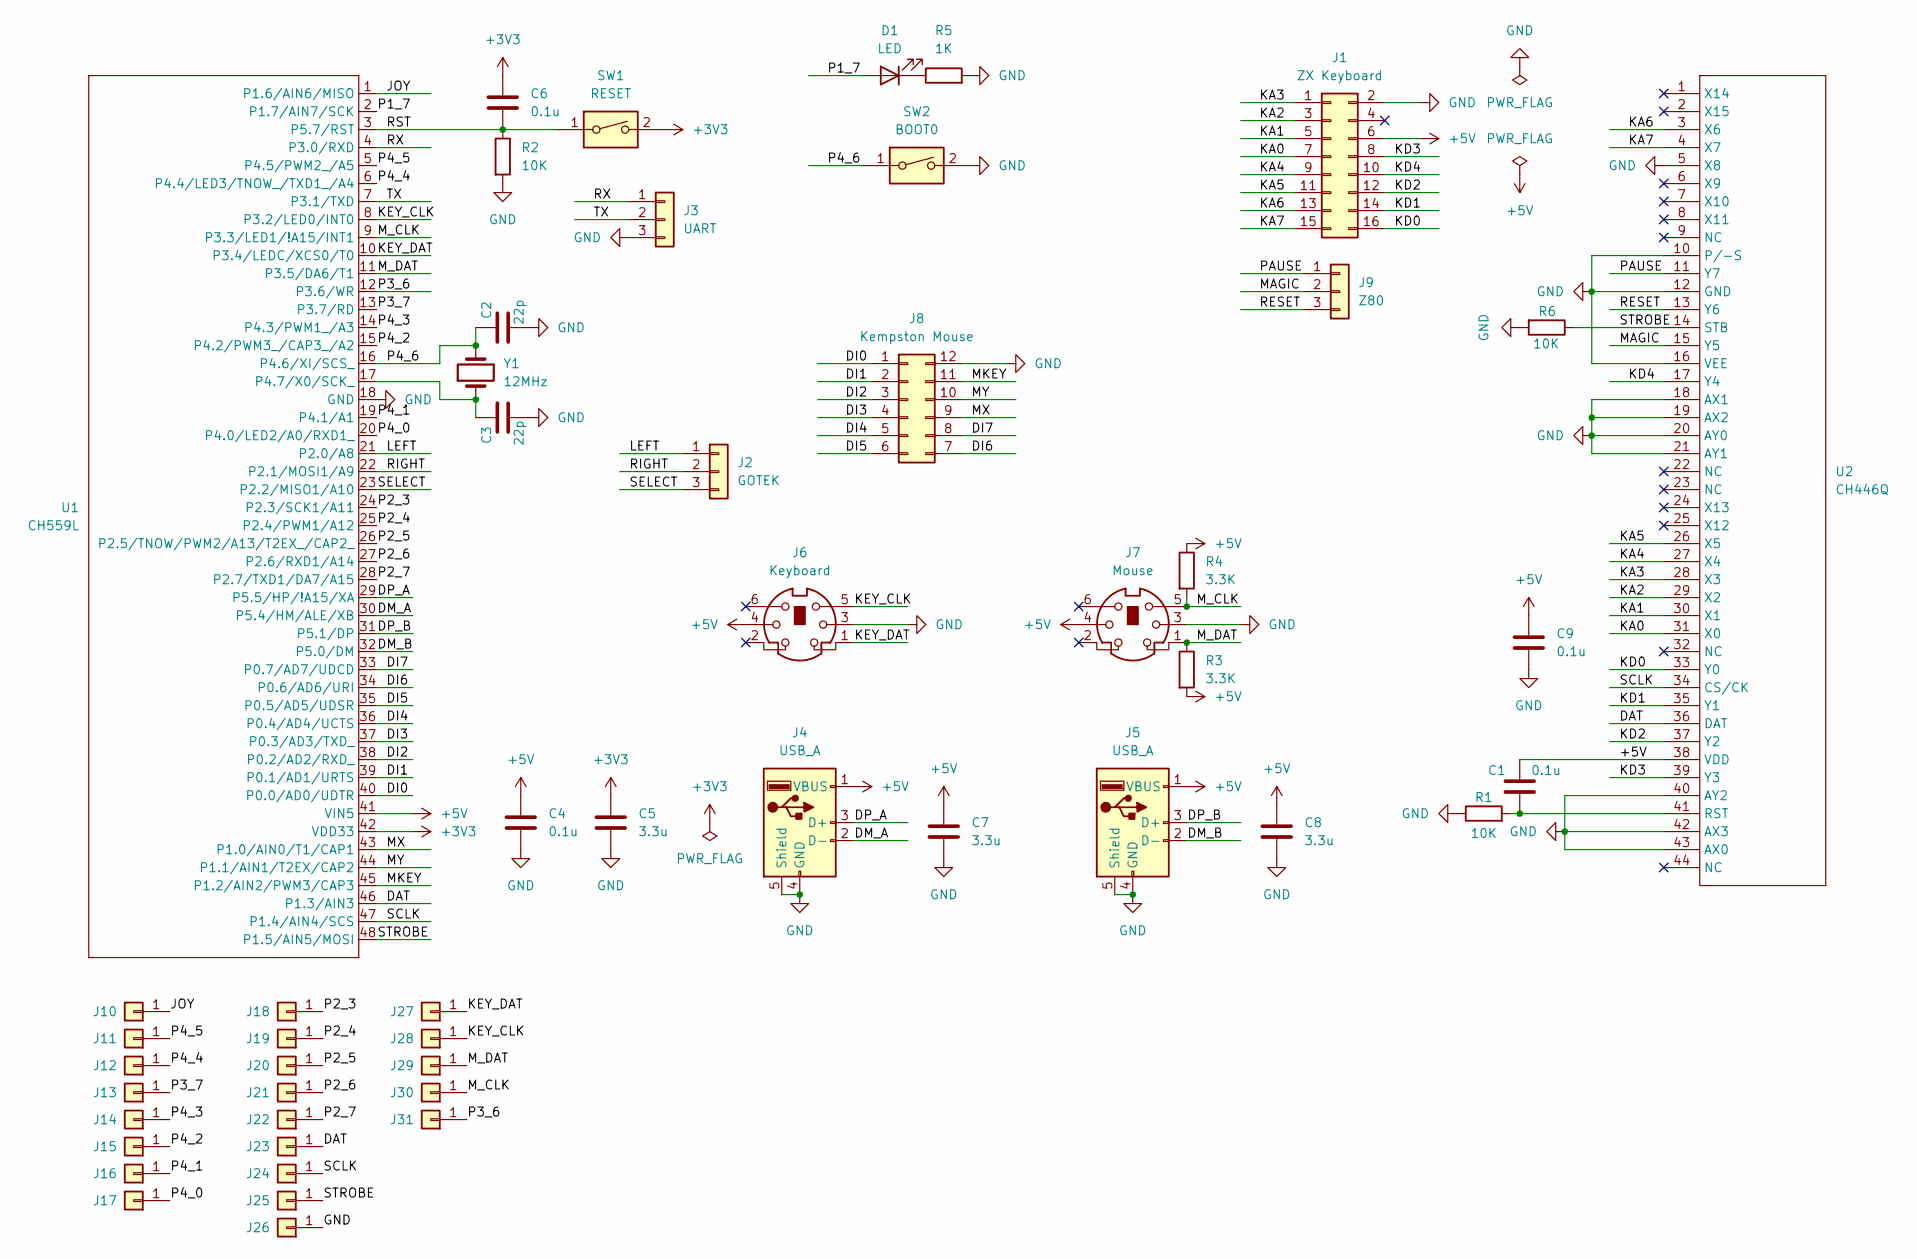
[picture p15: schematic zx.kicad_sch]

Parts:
C1, C4, C6, C9: 0.1u; C_1206_3216Metric_Pad1.33x1.80mm_HandSolder
C2, C3: 22p; C_1206_3216Metric_Pad1.33x1.80mm_HandSolder
C5, C7, C8: 3.3u; C_1206_3216Metric_Pad1.33x1.80mm_HandSolder
D1: LED; LED_1206_3216Metric_Pad1.42x1.75mm_HandSolder
J1: ZX Keyboard; PinHeader_2x08_P2.54mm_Vertical
J2: GOTEK; PinHeader_1x03_P2.54mm_Vertical
J3: UART; PinHeader_1x03_P2.54mm_Vertical
J4, J5: USB_A; USB_A_Stewart_SS-52100-001_Horizontal
J6: Keyboard; Connector_Mini-DIN_Female_6Pin_2rows
J7: Mouse; Connector_Mini-DIN_Female_6Pin_2rows
J8: Kempston Mouse; PinHeader_2x06_P2.54mm_Vertical
J9: Z80; PinHeader_1x03_P2.54mm_Vertical
J10, J11, J12, J13, J14, J15, J16, J17, J18, J19, J20, J21, J22, J23, J24, J25, J26, J27, J28, J29, J30, J31: Conn_01x01; THT_Pin_Vertical
R1, R2, R6: 10K; R_1206_3216Metric_Pad1.30x1.75mm_HandSolder
R3, R4: 3.3K; R_1206_3216Metric_Pad1.30x1.75mm_HandSolder
R5: 1K; R_1206_3216Metric_Pad1.30x1.75mm_HandSolder
SW1: RESET; PinHeader_1x02_P2.54mm_Vertical
SW2: BOOT0; PinHeader_1x02_P2.54mm_Vertical
U1: CH559L; LQFP-48_7x7mm_P0.5mm
U2: CH446Q; TQFP-44_10x10mm_P0.8mm
Y1: 12MHz; Crystal_HC49-4H_Vertical

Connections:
+3V3: C5.1, C6.1, SW1.2, U1.42 (VDD33)
+5V: C1.1, C4.1, C7.1, C8.1, C9.1, J1.6, J4.1 (VBUS), J5.1 (VBUS), J6.4, J7.4, R3.2, R4.1, U1.41 (VIN5), U2.38 (VDD)
/DAT: J23.1, U1.46 (P1.3/AIN3), U2.36 (DAT)
/DI0: J8.1, U1.40 (P0.0/AD0/UDTR)
/DI1: J8.2, U1.39 (P0.1/AD1/URTS)
/DI2: J8.3, U1.38 (P0.2/AD2/RXD_)
/DI3: J8.4, U1.37 (P0.3/AD3/TXD_)
/DI4: J8.5, U1.36 (P0.4/AD4/UCTS)
/DI5: J8.6, U1.35 (P0.5/AD5/UDSR)
/DI6: J8.7, U1.34 (P0.6/AD6/URI)
/DI7: J8.8, U1.33 (P0.7/AD7/UDCD)
/DM_A: J4.2 (D-), U1.30 (P5.4/HM/ALE/XB)
/DM_B: J5.2 (D-), U1.32 (P5.0/DM)
/DP_A: J4.3 (D+), U1.29 (P5.5/HP/!A15/XA)
/DP_B: J5.3 (D+), U1.31 (P5.1/DP)
/JOY: J10.1, U1.1 (P1.6/AIN6/MISO)
/KA0: J1.7, U2.31 (X0)
/KA1: J1.5, U2.30 (X1)
/KA2: J1.3, U2.29 (X2)
/KA3: J1.1, U2.28 (X3)
/KA4: J1.9, U2.27 (X4)
/KA5: J1.11, U2.26 (X5)
/KA6: J1.13, U2.3 (X6)
/KA7: J1.15, U2.4 (X7)
/KD0: J1.16, U2.33 (Y0)
/KD1: J1.14, U2.35 (Y1)
/KD2: J1.12, U2.37 (Y2)
/KD3: J1.8, U2.39 (Y3)
/KD4: J1.10, U2.17 (Y4)
/KEY_CLK: J6.5, J28.1, U1.8 (P3.2/LED0/INT0)
/KEY_DAT: J6.1, J27.1, U1.10 (P3.4/LEDC/XCS0/T0)
/LEFT: J2.1, U1.21 (P2.0/A8)
/MAGIC: J9.2, U2.15 (Y5)
/MKEY: J8.11, U1.45 (P1.2/AIN2/PWM3/CAP3)
/MX: J8.9, U1.43 (P1.0/AIN0/T1/CAP1)
/MY: J8.10, U1.44 (P1.1/AIN1/T2EX/CAP2)
/M_CLK: J7.5, J30.1, R4.2, U1.9 (P3.3/LED1/!A15/INT1)
/M_DAT: J7.1, J29.1, R3.1, U1.11 (P3.5/DA6/T1)
/P1_7: D1.2 (A), U1.2 (P1.7/AIN7/SCK)
/P2_3: J18.1, U1.24 (P2.3/SCK1/A11)
/P2_4: J19.1, U1.25 (P2.4/PWM1/A12)
/P2_5: J20.1, U1.26 (P2.5/TNOW/PWM2/A13/T2EX_/CAP2_)
/P2_6: J21.1, U1.27 (P2.6/RXD1/A14)
/P2_7: J22.1, U1.28 (P2.7/TXD1/DA7/A15)
/P3_6: J31.1, U1.12 (P3.6/WR)
/P3_7: J13.1, U1.13 (P3.7/RD)
/P4_0: J17.1, U1.20 (P4.0/LED2/A0/RXD1_)
/P4_1: J16.1, U1.19 (P4.1/A1)
/P4_2: J15.1, U1.15 (P4.2/PWM3_/CAP3_/A2)
/P4_3: J14.1, U1.14 (P4.3/PWM1_/A3)
/P4_4: J12.1, U1.6 (P4.4/LED3/TNOW_/TXD1_/A4)
/P4_5: J11.1, U1.5 (P4.5/PWM2_/A5)
/P4_6: C2.1, SW2.1, U1.16 (P4.6/XI/SCS_), Y1.2
/PAUSE: J9.1, U2.11 (Y7)
/RESET: J9.3, U2.13 (Y6)
/RIGHT: J2.2, U1.22 (P2.1/MOSI1/A9)
/RST: C6.2, R2.1, SW1.1, U1.3 (P5.7/RST)
/RX: J3.1, U1.4 (P3.0/RXD)
/SCLK: J24.1, U1.47 (P1.4/AIN4/SCS), U2.34 (CS/CK)
/SELECT: J2.3, U1.23 (P2.2/MISO1/A10)
/STROBE: J25.1, R6.1, U1.48 (P1.5/AIN5/MOSI), U2.14 (STB)
/TX: J3.2, U1.7 (P3.1/TXD)
GND: C2.2, C3.2, C4.2, C5.2, C7.2, C8.2, C9.2, J1.2, J3.3, J4.4 (GND), J4.5 (Shield), J5.4 (GND), J5.5 (Shield), J6.3, J7.3, J8.12, J26.1, R1.1, R2.2, R5.2, R6.2, SW2.2, U1.18 (GND), U2.5 (X8), U2.10 (P/-S), U2.12 (GND), U2.16 (VEE), U2.18 (AX1), U2.19 (AX2), U2.20 (AY0), U2.21 (AY1), U2.40 (AY2), U2.42 (AX3), U2.43 (AX0)
unnamed: D1.1 (K), R5.1
unnamed: C3.1, U1.17 (P4.7/X0/SCK_), Y1.1
unnamed: C1.2, R1.2, U2.41 (RST)

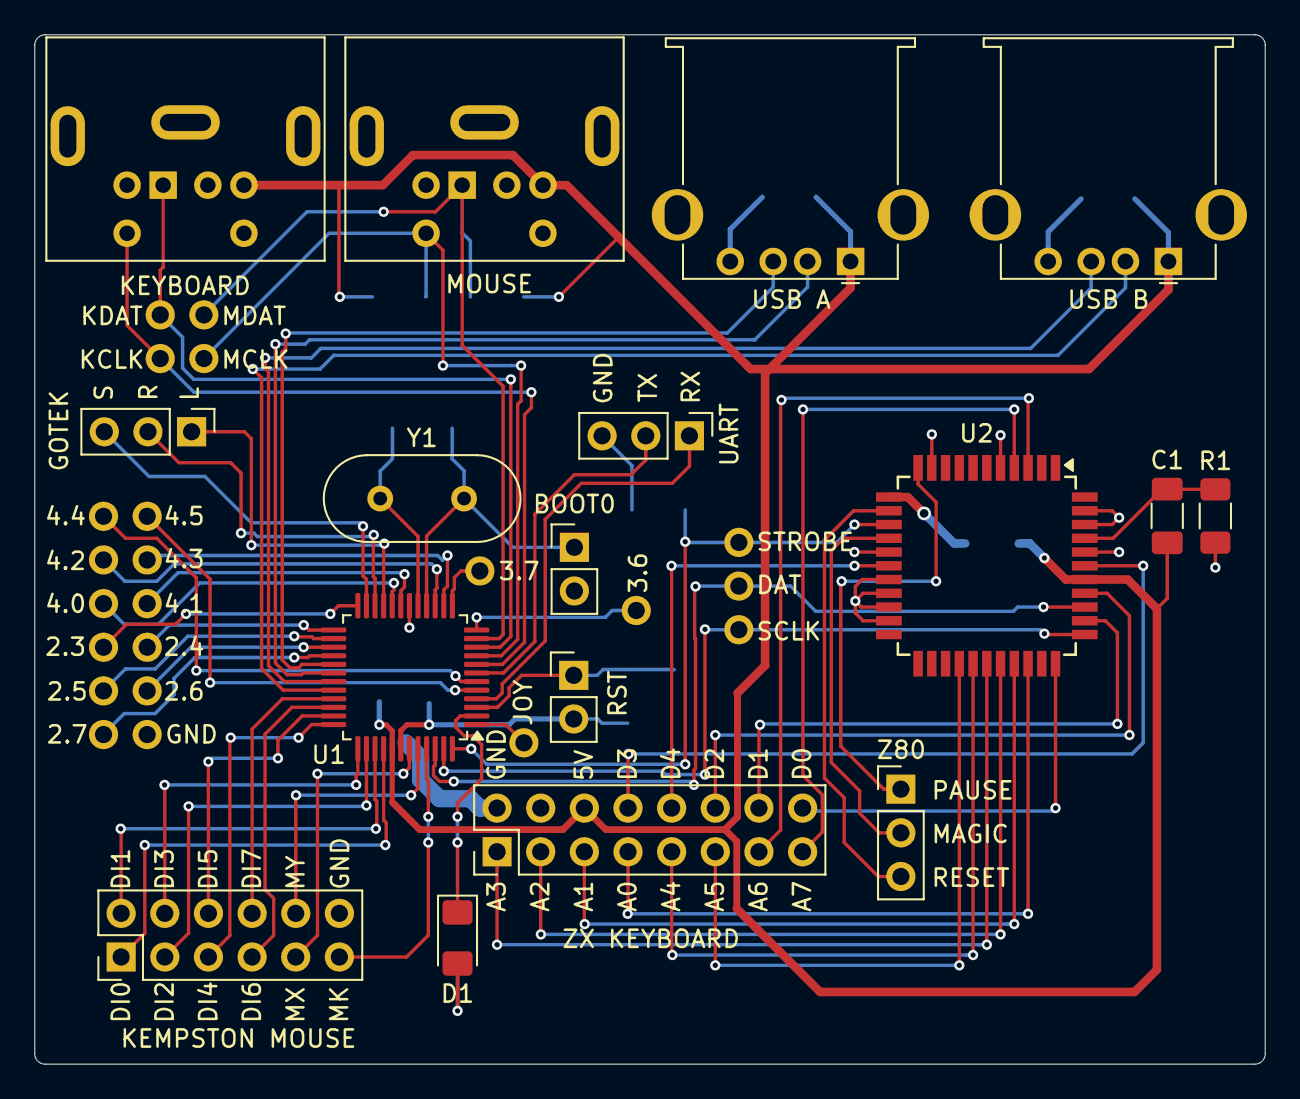
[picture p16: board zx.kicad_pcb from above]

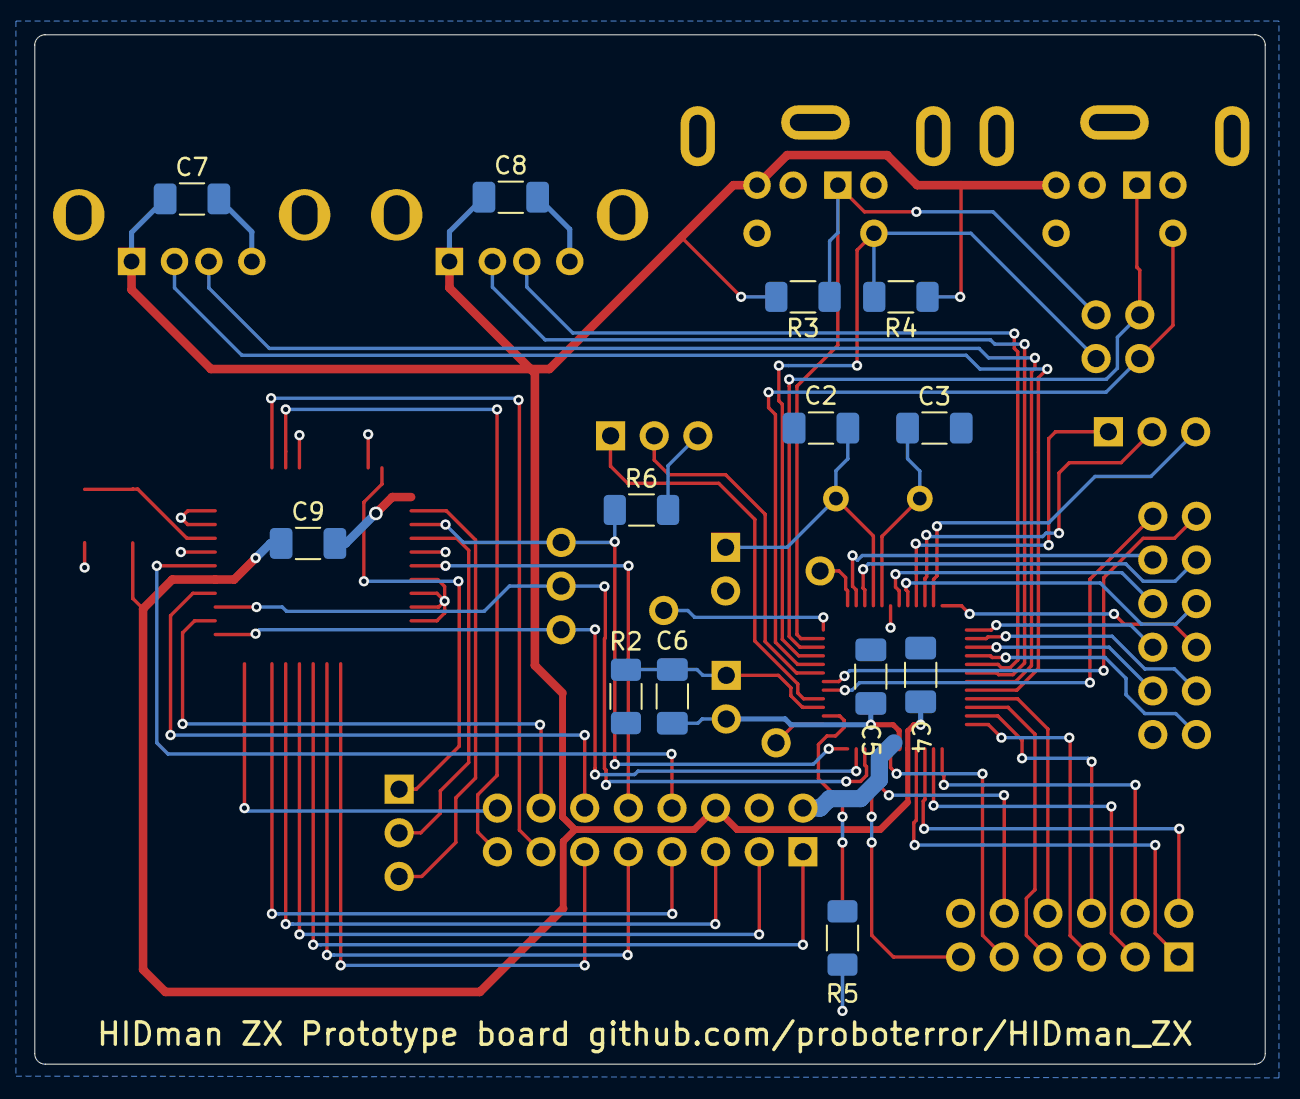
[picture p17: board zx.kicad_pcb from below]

Board: 2 copper layers, 71.6 x 59.9 mm, 52 parts (13 on the bottom side), 66 nets.

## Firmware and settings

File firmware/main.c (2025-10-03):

#include <stdio.h>
#include <stdint.h>
#include <stdbool.h>
#include "ch559.h"
#include "usbhost.h"
#include "uart.h"
#include "ps2protocol.h"
#include "parsedescriptor.h"
#include "mouse.h"
#include "keyboardled.h"
#include "settings.h"
#include "system.h"
#include "ps2_keyboard.h"
#include "ps2_mouse.h"
#include "kempston_joy.h"
#include "zx_keyboard.h"
#include "sega_pad.h"

uint8_t UsbUpdateCounter = 0;
volatile uint32_t __data time_ms_32 = 0;

void EveryMillisecond(void) {

	// Soft watchdog is to get around the fact that the real watchdog runs too fast
	SoftWatchdog++;
	if (SoftWatchdog > 5000) {
		// if soft watchdog overflows, just go into an infinite loop and we'll trigger the real watchdog
		DEBUGOUT("Soft overflow\n");
		while(1);
	}

	// otherwise, reset the real watchdog
	WDOG_COUNT = 0x00;
	// every 4 milliseconds (250hz), check one or the other USB port (so each gets checked at 125hz)
	if (UsbUpdateCounter == 4)
		s_CheckUsbPort0 = TRUE;
	else if (UsbUpdateCounter == 8){
		s_CheckUsbPort1 = TRUE;
		UsbUpdateCounter = 0;
	}

	UsbUpdateCounter++;

	// Turn current LED on if we haven't seen any activity in a while
	if (LEDDelayMs) {
		LEDDelayMs--;
	} else {
		setLED(true);
	}

	time_ms_32++;
}



// timer should run at 48MHz divided by (0xFFFF - (TH0TL0))
// i.e. 60khz
void mTimer0Interrupt(void) __interrupt(INT_NO_TMR0)
{
	static uint8_t msDiv = 0;
	if (++msDiv == 60) {
		msDiv = 0;
		EveryMillisecond();
	}

}

// With SDCC prototypes for the interrupts must be visible in the context of the main() function.
void ext0_interrupt(void) __interrupt(INT_NO_INT0);
void ext1_interrupt(void) __interrupt(INT_NO_INT1);

int main(void)
{
	bool WatchdogReset = 0;

	// Watchdog happened, go to "safe mode"
	if (!(PCON & bRST_FLAG0) && (PCON & bRST_FLAG1)){
		WatchdogReset = 1;
	}

	GPIOInit();

	//delay a bit, without using the builtin functions
	UsbUpdateCounter = 255;
	while (--UsbUpdateCounter);

#if defined(OSC_EXTERNAL)
	if (!(P3 & (1 << 6))) runBootloader();
#endif

	ClockInit();
    mDelaymS(500);   
	
	InitUART0();

	InitUsbData();
	InitUsbHost();

	InitMice();

	ps2_keyboard_init();
	ps2_mouse_init_registers();
	kempston_joy_init();
	zx_keyboard_init();
	sega_pad_init();

	// timer0 setup
	TMOD = (TMOD & 0xf0) | 0x02; // mode 1 (8bit auto reload)
	TH0 = 0xBD;					 // 60khz

	TR0 = 1; // start timer0
	ET0 = 1; //enable timer0 interrupt;

	EA = 1;	 // enable all interrupts

	if (WatchdogReset) DEBUGOUT("Watchdog reset detected (%x), entering safemode\n", PCON);

	InitSettings();

	// enable watchdog
	WDOG_COUNT = 0x00;
	SAFE_MOD = 0x55;
	SAFE_MOD = 0xAA;
	GLOBAL_CFG |= bWDOG_EN;

	WDOG_COUNT = 0x00;

	DEBUGOUT("ok\n");

	// main loop
	while (1)
	{
		// reset watchdog
		SoftWatchdog = 0;

		if(s_CheckUsbPort0)
			sega_pad_update(); // Poll every 8 ms

		ProcessUsbHostPort();
		HandleMouse();
		
		kempston_joy_update();
		ps2_mouse_update();
		zx_keyboard_update();
	}
}

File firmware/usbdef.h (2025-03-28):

#ifndef __USB_DEF__
#define __USB_DEF__

#ifdef __cplusplus
extern "C" {
#endif

/*----- USB constant and structure define --------------------------------*/

/* USB PID */
#ifndef USB_PID_SETUP
#define USB_PID_NULL            0x00    /* reserved PID */
#define USB_PID_SOF             0x05
#define USB_PID_SETUP           0x0D
#define USB_PID_IN              0x09
#define USB_PID_OUT             0x01
#define USB_PID_ACK             0x02
#define USB_PID_NAK             0x0A
#define USB_PID_STALL           0x0E
#define USB_PID_DATA0           0x03
#define USB_PID_DATA1           0x0B
#define USB_PID_PRE             0x0C
#endif

/* USB standard device request code */
#ifndef USB_GET_DESCRIPTOR
#define USB_GET_STATUS          0x00
#define USB_CLEAR_FEATURE       0x01
#define USB_SET_FEATURE         0x03
#define USB_SET_ADDRESS         0x05
#define USB_GET_DESCRIPTOR      0x06
#define USB_SET_DESCRIPTOR      0x07
#define USB_GET_CONFIGURATION   0x08
#define USB_SET_CONFIGURATION   0x09
#define USB_GET_INTERFACE       0x0A
#define USB_SET_INTERFACE       0x0B
#define USB_SYNCH_FRAME         0x0C
#endif

/* USB hub class request code */
#ifndef HUB_GET_DESCRIPTOR
#define HUB_GET_STATUS          0x00
#define HUB_CLEAR_FEATURE       0x01
#define HUB_GET_STATE           0x02
#define HUB_SET_FEATURE         0x03
#define HUB_GET_DESCRIPTOR      0x06
#define HUB_SET_DESCRIPTOR      0x07
#endif

/* USB HID class request code */
#ifndef HID_GET_REPORT
#define HID_GET_REPORT          0x01
#define HID_GET_IDLE            0x02
#define HID_GET_PROTOCOL        0x03
#define HID_SET_REPORT          0x09
#define HID_SET_IDLE            0x0A
#define HID_SET_PROTOCOL        0x0B
#endif

/* HID Report Types */
#define HID_REPORT_INPUT                0x01
#define HID_REPORT_OUTPUT               0x02
#define HID_REPORT_FEATURE              0x03


/* Bit define for USB request type */
#ifndef USB_REQ_TYP_MASK
#define USB_REQ_TYP_IN          0x80            /* control IN, device to host */
#define USB_REQ_TYP_OUT         0x00            /* control OUT, host to device */
#define USB_REQ_TYP_READ        0x80            /* control read, device to host */
#define USB_REQ_TYP_WRITE       0x00            /* control write, host to device */
#define USB_REQ_TYP_MASK        0x60            /* bit mask of request type */
#define USB_REQ_TYP_STANDARD    0x00
#define USB_REQ_TYP_CLASS       0x20
#define USB_REQ_TYP_VENDOR      0x40
#define USB_REQ_TYP_RESERVED    0x60
#define USB_REQ_RECIP_MASK      0x1F            /* bit mask of request recipient */
#define USB_REQ_RECIP_DEVICE    0x00
#define USB_REQ_RECIP_INTERF    0x01
#define USB_REQ_RECIP_ENDP      0x02
#define USB_REQ_RECIP_OTHER     0x03
#endif

/* USB request type for hub class request */
#ifndef HUB_GET_HUB_DESCRIPTOR
#define HUB_CLEAR_HUB_FEATURE   0x20
#define HUB_CLEAR_PORT_FEATURE  0x23
#define HUB_GET_BUS_STATE       0xA3
#define HUB_GET_HUB_DESCRIPTOR  0xA0
#define HUB_GET_HUB_STATUS      0xA0
#define HUB_GET_PORT_STATUS     0xA3
#define HUB_SET_HUB_DESCRIPTOR  0x20
#define HUB_SET_HUB_FEATURE     0x20
#define HUB_SET_PORT_FEATURE    0x23
#endif

/* Hub class feature selectors */
#ifndef HUB_PORT_RESET
#define HUB_C_HUB_LOCAL_POWER   0
#define HUB_C_HUB_OVER_CURRENT  1
#define HUB_PORT_CONNECTION     0
#define HUB_PORT_ENABLE         1
#define HUB_PORT_SUSPEND        2
#define HUB_PORT_OVER_CURRENT   3
#define HUB_PORT_RESET          4
#define HUB_PORT_POWER          8
#define HUB_PORT_LOW_SPEED      9
#define HUB_C_PORT_CONNECTION   16
#define HUB_C_PORT_ENABLE       17
#define HUB_C_PORT_SUSPEND      18
#define HUB_C_PORT_OVER_CURRENT 19
#define HUB_C_PORT_RESET        20
#endif

/* USB descriptor type */
#ifndef USB_DESCR_TYP_DEVICE
#define USB_DESCR_TYP_DEVICE    0x01
#define USB_DESCR_TYP_CONFIG    0x02
#define USB_DESCR_TYP_STRING    0x03
#define USB_DESCR_TYP_INTERF    0x04
#define USB_DESCR_TYP_ENDP      0x05
#define USB_DESCR_TYP_QUALIF    0x06
#define USB_DESCR_TYP_SPEED     0x07
#define USB_DESCR_TYP_OTG       0x09
#define USB_DESCR_TYP_HID       0x21
#define USB_DESCR_TYP_REPORT    0x22
#define USB_DESCR_TYP_PHYSIC    0x23
#define USB_DESCR_TYP_CS_INTF   0x24
#define USB_DESCR_TYP_CS_ENDP   0x25
#define USB_DESCR_TYP_HUB       0x29
#endif

/* USB device class */
#ifndef USB_DEV_CLASS_HUB
#define USB_DEV_CLASS_RESERVED  0x00
#define USB_DEV_CLASS_AUDIO     0x01
#define USB_DEV_CLASS_COMMUNIC  0x02
#define USB_DEV_CLASS_HID       0x03
#define USB_DEV_CLASS_MONITOR   0x04
#define USB_DEV_CLASS_PHYSIC_IF 0x05
#define USB_DEV_CLASS_POWER     0x06
#define USB_DEV_CLASS_PRINTER   0x07
#define USB_DEV_CLASS_STORAGE   0x08
#define USB_DEV_CLASS_HUB       0x09
#define USB_DEV_CLASS_VEN_SPEC  0xFF
#endif
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

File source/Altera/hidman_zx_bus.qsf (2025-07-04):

# -------------------------------------------------------------------------- #
#
# Copyright (C) 1991-2010 Altera Corporation
# Your use of Altera Corporation's design tools, logic functions 
# and other software and tools, and its AMPP partner logic 
# functions, and any output files from any of the foregoing 
# (including device programming or simulation files), and any 
# associated documentation or information are expressly subject 
# to the terms and conditions of the Altera Program License 
# Subscription Agreement, Altera MegaCore Function License 
# Agreement, or other applicable license agreement, including, 
# without limitation, that your use is for the sole purpose of 
# programming logic devices manufactured by Altera and sold by 
# Altera or its authorized distributors.  Please refer to the 
# applicable agreement for further details.
#
# -------------------------------------------------------------------------- #
#
# Quartus II
# Version 9.1 Build 350 03/24/2010 Service Pack 2 SJ Web Edition
# Date created = 19:35:27  January 23, 2024
#
# -------------------------------------------------------------------------- #
#
# Notes:
#
# 1) The default values for assignments are stored in the file:
#		test_assignment_defaults.qdf
#    If this file doesn't exist, see file:
#		assignment_defaults.qdf
#
# 2) Altera recommends that you do not modify this file. This
#    file is updated automatically by the Quartus II software
#    and any changes you make may be lost or overwritten.
#
# -------------------------------------------------------------------------- #


set_global_assignment -name FAMILY MAX3000A
set_global_assignment -name DEVICE "EPM3128ATC100-10"
set_global_assignment -name TOP_LEVEL_ENTITY hidman_zx_bus
set_global_assignment -name ORIGINAL_QUARTUS_VERSION "9.1 SP2"
set_global_assignment -name PROJECT_CREATION_TIME_DATE "19:35:27  JANUARY 23, 2024"
set_global_assignment -name LAST_QUARTUS_VERSION "13.0 SP1"
set_global_assignment -name USE_GENERATED_PHYSICAL_CONSTRAINTS OFF -section_id eda_blast_fpga
set_global_assignment -name DEVICE_FILTER_PACKAGE TQFP
set_global_assignment -name RESERVE_ALL_UNUSED_PINS_NO_OUTPUT_GND "AS INPUT TRI-STATED"
set_global_assignment -name MAX7000_DEVICE_IO_STANDARD "3.3-V LVTTL"
set_global_assignment -name MAX7000_OPTIMIZATION_TECHNIQUE AREA
set_global_assignment -name SYNTH_TIMING_DRIVEN_SYNTHESIS OFF
set_global_assignment -name OPTIMIZE_HOLD_TIMING OFF
set_global_assignment -name FITTER_EFFORT "STANDARD FIT"
set_global_assignment -name OPTIMIZE_IOC_REGISTER_PLACEMENT_FOR_TIMING OFF
set_global_assignment -name AUTO_PARALLEL_EXPANDERS OFF
set_global_assignment -name RTLV_GROUP_RELATED_NODES_TMV ON
set_global_assignment -name RTLV_GROUP_COMB_LOGIC_IN_CLOUD_TMV OFF
set_location_assignment PIN_25 -to D[7]
set_location_assignment PIN_35 -to D[6]
set_location_assignment PIN_37 -to D[5]
set_location_assignment PIN_41 -to D[3]
set_location_assignment PIN_44 -to D[4]
set_location_assignment PIN_31 -to D[2]
set_location_assignment PIN_29 -to D[1]
set_location_assignment PIN_28 -to D[0]
set_location_assignment PIN_20 -to DI[7]
set_location_assignment PIN_19 -to DI[6]
set_location_assignment PIN_17 -to DI[5]
set_location_assignment PIN_16 -to DI[4]
set_location_assignment PIN_14 -to DI[3]
set_location_assignment PIN_13 -to DI[2]
set_location_assignment PIN_12 -to DI[1]
set_location_assignment PIN_10 -to DI[0]
set_location_assignment PIN_47 -to IORQ
set_location_assignment PIN_57 -to M1
set_location_assignment PIN_7 -to MKEY
set_location_assignment PIN_9 -to MX
set_location_assignment PIN_8 -to MY
set_location_assignment PIN_48 -to RD
set_location_assignment PIN_45 -to IORQGE
set_global_assignment -name INCREMENTAL_COMPILATION OFF
set_location_assignment PIN_32 -to A[0]
set_location_assignment PIN_36 -to A[1]
set_location_assignment PIN_40 -to A[2]
set_location_assignment PIN_42 -to A[3]
set_location_assignment PIN_56 -to A[4]
set_location_assignment PIN_55 -to A[5]
set_location_assignment PIN_54 -to A[6]
set_location_assignment PIN_52 -to A[7]
set_location_assignment PIN_58 -to A[8]
set_location_assignment PIN_60 -to A[9]
set_location_assignment PIN_61 -to A[10]
set_location_assignment PIN_63 -to A[11]
set_location_assignment PIN_23 -to A[12]
set_location_assignment PIN_24 -to A[13]
set_location_assignment PIN_21 -to A[14]
set_location_assignment PIN_22 -to A[15]
set_location_assignment PIN_27 -to DOS
set_location_assignment PIN_6 -to DAT
set_location_assignment PIN_5 -to SK
set_location_assignment PIN_2 -to STB
set_location_assignment PIN_1 -to JOY
set_location_assignment PIN_46 -to NMI
set_location_assignment PIN_49 -to BSRQ
set_location_assignment PIN_64 -to JOY_ENABLE
set_global_assignment -name AUTO_TURBO_BIT AUTO
set_global_assignment -name EDA_SIMULATION_TOOL "ModelSim-Altera (SystemVerilog)"
set_global_assignment -name OPTIMIZE_MULTI_CORNER_TIMING OFF
set_global_assignment -name EDA_DESIGN_INSTANCE_NAME NA -section_id testbench
set_global_assignment -name EDA_TEST_BENCH_MODULE_NAME testbench -section_id testbench
set_location_assignment PIN_67 -to RST_IN
set_location_assignment PIN_50 -to RST_OUT
set_location_assignment PIN_30 -to CLK
set_location_assignment PIN_68 -to TAPE_IN
set_global_assignment -name VERILOG_FILE hidman_zx_bus.v -hdl_version SystemVerilog_2005
set_global_assignment -name EDA_OUTPUT_DATA_FORMAT "SYSTEMVERILOG HDL" -section_id eda_simulation
set_global_assignment -name EDA_TIME_SCALE "1 ps" -section_id eda_simulation
set_global_assignment -name EDA_TEST_BENCH_ENABLE_STATUS TEST_BENCH_MODE -section_id eda_simulation
set_global_assignment -name EDA_NATIVELINK_SIMULATION_TEST_BENCH testbench -section_id eda_simulation
set_global_assignment -name EDA_TEST_BENCH_NAME testbench -section_id eda_simulation
set_global_assignment -name EDA_TEST_BENCH_FILE testbench.v -section_id testbench -hdl_version SystemVerilog_2005

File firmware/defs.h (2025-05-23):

#ifndef __DEFS_H__
#define __DEFS_H__
#include <stdint.h>
#include <stdbool.h>
#include <string.h>
#include "type.h"
#include "andyalloc.h"
#include "linkedlist.h"

#define ROOT_HUB_COUNT 2

#define MAX_EXHUB_PORT_COUNT 4
#define EXHUB_PORT_NONE 0xff
#define MAX_INTERFACE_COUNT 4
#define MAX_ENDPOINT_COUNT 4
#define MAX_EXHUB_LEVEL 1
#define ENDPOINT_OUT 0
#define ENDPOINT_IN 1

#define ERR_SUCCESS 0x00
#define ERR_USB_CONNECT 0x15
#define ERR_USB_DISCON 0x16
#define ERR_USB_BUF_OVER 0x17
#define ERR_USB_DISK_ERR 0x1F
#define ERR_USB_TRANSFER 0x20
#define ERR_USB_UNSUPPORT 0xFB
#define ERR_USB_UNKNOWN 0xFE

#define ROOT_DEVICE_DISCONNECT 0
#define ROOT_DEVICE_CONNECTED 1
#define ROOT_DEVICE_FAILED 2
#define ROOT_DEVICE_SUCCESS 3

/*#define DEV_TYPE_KEYBOARD   ( USB_DEV_CLASS_HID | 0x20 )
#define DEV_TYPE_MOUSE      ( USB_DEV_CLASS_HID | 0x30 )
#define DEV_TYPE_JOYSTICK      ( USB_DEV_CLASS_HID | 0x40 )
#define DEV_TYPE_GAMEPAD      ( USB_DEV_CLASS_HID | 0x50 )*/

#define HID_SEG_KEYBOARD_MODIFIER_INDEX 0
#define HID_SEG_KEYBOARD_VAL_INDEX 1
#define HID_SEG_BUTTON_INDEX 2
#define HID_SEG_X_INDEX 3
#define HID_SEG_Y_INDEX 4
#define HID_SEG_WHEEL_INDEX 5

#define REPORT_USAGE_PAGE 0x04
#define REPORT_USAGE 0x08
#define REPORT_LOCAL_MINIMUM 0x14
#define REPORT_LOCAL_MAXIMUM 0x24
#define REPORT_PHYSICAL_MINIMUM 0x34
#define REPORT_PHYSICAL_MAXIMUM 0x44
#define REPORT_USAGE_MINIMUM 0x18
#define REPORT_USAGE_MAXIMUM 0x28

#define TYPE_MAIN 0
#define TYPE_GLOBAL 1
#define TYPE_LOCAL 2

#define REPORT_UNIT 0x64
#define REPORT_INPUT 0x80
#define REPORT_OUTPUT 0x90
#define REPORT_FEATURE 0xB0

#define REPORT_REPORT_SIZE 0x74
#define REPORT_REPORT_ID 0x84
#define REPORT_REPORT_COUNT 0x94

#define REPORT_COLLECTION 0xA0
#define REPORT_COLLECTION_END 0xC0

#define REPORT_USAGE_UNKNOWN 0x00
#define REPORT_USAGE_POINTER 0x01
#define REPORT_USAGE_MOUSE 0x02
#define REPORT_USAGE_RESERVED 0x03
#define REPORT_USAGE_JOYSTICK 0x04
#define REPORT_USAGE_GAMEPAD 0x05
#define REPORT_USAGE_KEYBOARD 0x06
#define REPORT_USAGE_KEYPAD 0x07
#define REPORT_USAGE_MULTI_AXIS 0x08
#define REPORT_USAGE_SYSTEM 0x09

#define REPORT_USAGE_X 0x30
#define REPORT_USAGE_Y 0x31
#define REPORT_USAGE_Z 0x32
#define REPORT_USAGE_Rx 0x33
#define REPORT_USAGE_Ry 0x34
#define REPORT_USAGE_Rz 0x35
#define REPORT_USAGE_WHEEL 0x38
#define REPORT_USAGE_HATSWITCH 0x39

#define REPORT_USAGE_PAGE_GENERIC 0x01
#define REPORT_USAGE_PAGE_KEYBOARD 0x07
#define REPORT_USAGE_PAGE_LEDS 0x08
#define REPORT_USAGE_PAGE_BUTTON 0x09
#define REPORT_USAGE_PAGE_VENDOR 0xff00

#define HID_LOCAL_ITEM_TAG_USAGE 0x00
#define HID_LOCAL_ITEM_TAG_USAGE_MIN 0x01
#define HID_LOCAL_ITEM_TAG_USAGE_MAX 0x02

#define HID_GLOBAL_ITEM_TAG_USAGE_PAGE 0x00
#define HID_GLOBAL_ITEM_TAG_LOGICAL_MINIMUM 0x01
#define HID_GLOBAL_ITEM_TAG_LOGICAL_MAXIMUM 0x02
#define HID_GLOBAL_ITEM_TAG_PHYSICAL_MINIMUM 0x03
#define HID_GLOBAL_ITEM_TAG_PHYSICAL_MAXIMUM 0x04
#define HID_GLOBAL_ITEM_TAG_REPORT_SIZE 0x07
#define HID_GLOBAL_ITEM_TAG_REPORT_ID 0x08
#define HID_GLOBAL_ITEM_TAG_REPORT_COUNT 0x09

#define HID_MAIN_ITEM_TAG_INPUT 0x08
#define HID_MAIN_ITEM_TAG_COLLECTION_START 0x0A
#define HID_MAIN_ITEM_TAG_COLLECTION_END 0x0C

#define HID_INPUT_VARIABLE 0x02

#define HID_COLLECTION_APPLICATION 0x01

#define HID_ITEM_FORMAT_SHORT 0
#define HID_ITEM_FORMAT_LONG 1

#define HID_ITEM_TAG_LONG 15

#define MAX_HID_DEVICES 8

#define SIGNEX(v, sb) ((v) | (((v) & (1 << (sb))) ? ~((1 << (sb))-1) : 0))

typedef struct _EndPoint
{
	unsigned char EndpointAddr;
	unsigned short MaxPacketSize;

	unsigned char EndpointDir : 1;
	unsigned char TOG : 1;
} EndPoint, *PEndPoint;

typedef struct _HID_GLOBAL
{
	uint8_t usagePage;
	int32_t logicalMinimum;
	uint32_t logicalMaximum;
	INT8 physicalMinimum;
	INT8 physicalMaximum;
	uint8_t unitExponent;
	uint8_t unit;
	uint8_t reportID;
	uint8_t reportSize;
	uint8_t reportCount;
} HID_GLOBAL;

typedef struct _HID_LOCAL
{
	uint32_t usage;
	uint32_t usageMin;
	uint32_t usageMax;

} HID_LOCAL;

// maps a joystick control to a keyboard or mouse output

#define MAP_KEYBOARD 0
#define MAP_MOUSE 1
#define MAP_KEMPSTON 2

#define MAP_KEMPSTON_R 0
#define MAP_KEMPSTON_L 1
#define MAP_KEMPSTON_D 2
#define MAP_KEMPSTON_U 3
#define MAP_KEMPSTON_BUTTON1 4
#define MAP_KEMPSTON_BUTTON2 5
#define MAP_KEMPSTON_BUTTON3 6
#define MAP_KEMPSTON_BUTTON4 7

#define MAP_MOUSE_BUTTON1 1
#define MAP_MOUSE_BUTTON2 2
#define MAP_MOUSE_BUTTON3 3
#define MAP_MOUSE_BUTTON4 4
#define MAP_MOUSE_BUTTON5 5
#define MAP_MOUSE_X 4
#define MAP_MOUSE_Y 5
#define MAP_MOUSE_WHEEL 6

#define MAP_TYPE_NONE 0
#define MAP_TYPE_THRESHOLD_BELOW 1
#define MAP_TYPE_THRESHOLD_ABOVE 2
#define MAP_TYPE_SCALE 3
#define MAP_TYPE_ARRAY 4
#define MAP_TYPE_BITFIELD 5
#define MAP_TYPE_EQUAL 6
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

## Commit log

2025-03-28 Delete unused PS/2 protocol support code.
    Delete PS/2 specific mouse state.
    Delete key press repeat code.
    Delete HID keyboard LEDs state control code.
    Cleanup includes.
    Replace include guards with pragma once.
    [main.c]
2025-03-28 Port PS/2=>ZX keyboard support from https://github.com/proboterror/zx-rgbi-to-vga-hdmi_gotek-osd
    Add PS/2 keyboard support, clock connected to INT0 external interrupt.
    Receive 250 ms timeout disabled. Parity errors ignored (same as in RP2040 implementation).
    Connections:
    KEY_CLOCK: P3.2,
    KEY_DATA: P3.4 (conflicted with S1 runBootloader switch).
    Pins configured as PIN_MODE_OUTPUT_OPEN_DRAIN (Open drain output, no pull-up, support input).
    Add ZX Spectrum keyboard matrix support. FF OSD buttons support disabled.
    Add 8x16 Analog Switch Array Chip CH446Q support.
    Connections:
    CH446Q_DATA_PIN: P3.5
    CH446Q_SCLK_PIN: P3.6
    CH446Q_STROBE_PIN: P3.7
    Pins configured as PIN_MODE_INPUT_OUTPUT_PULLUP (Wea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
    [CH446Q.c, main.c, system.c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]
2025-03-28 Redirect USB HID keyboard key events to PS/2=>ZX keyboard processing chain. HID key code converted to PS/2 set make/break code, appended to PS/2 keyboard receive buffer, and further extracted in zx_k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
    ToDo: consider pass HID key code and state to zx_keyboard with buffering.
2025-03-28 Delete pwm.
    Add mockup for USB activity LED.
    ToDo: reset activity LED on PS/2 key scancodes buffer add or get.
    [main.c]
2025-03-28 Async PS/2 mouse interface support. Ported from https://github.com/proboterror/ZX_BUS_Mouse/tree/interrupt_processing_async
    Tested with external 3.3K pullup resistors on PS/2 mouse clock / data lines.
    CH446Q pins moved to CH559 port 1.
    Notable differences from AVR ATmega8 / ZX_BUS_Mouse implementation:
    Timeout timer set from external common timer 0 handler.
    ps2_init_port:
    // Release clock and data lines.
    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
2025-03-28 GOTEK floppy drive emulator keyboard=>GOTEK buttons interface.
2025-03-28 Set action/boot button pin to P3.6 (open collector input with internal pullup). Reserve P1.6 as keyboard activity LED output (push pull output).
    Switch GOTEK buttons pins to open collector with external pullups.
    Update GPIOInit (mostly duplicated / unused / obsolete by modules init).
2025-03-28 Set P1.6 as keyboard LED.
2025-03-28 USB mouse => PS/2 mouse => ZX Kempston mouse controller registers update chain.
    Init OutputMice structure.
    Unused mouse set methods cleanup.
2025-03-28 Add empty HIDMAN_ZX KiCad project. Add CH559L symbol library (symbol CH559L_1_1 copy from ../libs/ps2usb.kicad_sym).
    [zx.kicad_pcb, zx.kicad_sch]
2025-03-28 Add PS/2 Mini DIN connector footprint.
2025-03-28 Change Mini DIN connector drill holes diameter from 0.8 to 0.9 mm.
2025-03-28 KiCad schematic.
    [zx.kicad_sch]
2025-03-28 Initial PCB layout.
    [zx.kicad_pcb, zx.kicad_sch]
2025-03-28 PCB: replace +5V front face fill with tracks.
    [zx.kicad_pcb]
2025-03-28 Sync PCB footprints designators with schematic. Hide PCB footprints designators text. Add footprints description text. Alter GND in track.
    [zx.kicad_pcb]
2025-03-28 CH446Q output Z80 control signals PAUSE, MAGIC, RESET have common input connected to GND.
    [zx.kicad_pcb, zx.kicad_sch]
2025-04-01 Reserve P1.6 for Kempston Joystick DI write strobe (JOY). Move activity LED to P1.7. Add free-standing GND pin. Add J8 GND label.
    [zx.kicad_pcb, zx.kicad_sch]
2025-04-01 Add PS/2 keyboard/mouse debug pins.
    [zx.kicad_pcb, zx.kicad_sch]
2025-04-01 Rounded PCB corners.
    [zx.kicad_pcb]
2025-04-11 ZX BUS board draft schematic. CH446Q replaced with registers implementation, keeping serial interface.
    EPM3128ATC100 KiCad symbol source: own work.
    [hidman_zx_bus.kicad_pcb, hidman_zx_bus.kicad_sch]
2025-04-11 ZX BUS adapter EPM3128ATC100 Verilog implementation and testbench.
    107/128 macrocells.
    Simulation passed testbench tests.
    Implemented:
    - Kempston Mouse registers
    - Kempston Joystick 8-bit register
    - 40-key keyboard matrix on port #FE with serial interface compatible with CH446Q
    - Special keys for PAUSE, MAGIC, RESET (Z80 BSRQ/, NMI/, RESET/ control)
    - Reset keyboard registers state on incoming RESET
    - Option to disable Kempston Joystick interface (JOY_ENABLE pin)
    Disabled:
    - Mouse IORQGE
    - Mouse set registers initial values on reset
    - Joystick set registers initial values on reset
    Not implemented:
    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
    [hidman_zx_bus.qsf]
2025-04-22 Enable mouse controller registers reset. Testbench: enable mouse controller registers reset test.
    Set definition language as System Verilog.
    Alternate keyboard half_rows_state implementation.
    Add reserved external signals CLK, TAPE_IN.
    Extended comments.
    [hidman_zx_bus.qsf]
2025-04-24 Add "IP4220CZ6 Dual USB 2.0 ESD Protection TVS Array" KiCad symbol and datasheet. Symbol source: https://github.com/psk7/scorpion-card-pub/blob/master/revB/pcb/card.kicad_sch
2025-04-24 Add Würth Elektronik "WR-COM USB 2.0 Up Right 614004134726" connector datasheet and 3D model. Source: https://www.we-online.com/catalog/en/article/614004134726
    [WR-COM USB 2.0 Up Right 614004134726 (rev1).stp]
2025-04-24 Add Mini DIN 6 connector 3D model. Source: https://www.3dcontentcentral.com/download-model.aspx?catalogid=171&id=93513
    [MINI-DIN-6.stp]
2025-04-26 Route ZX BUS card PCB.
    [hidman_zx_bus.kicad_pcb, hidman_zx_bus.kicad_sch]
2025-04-26 Add ZX-BUS board description.
2025-05-10 Interrupt safe keyboard buffer update.
2025-05-11 Fixed pinMode with PIN_MODE_OUTPUT. Error sourced from https://github.com/atc1441/CH559sdccUSBHost
    [system.c]
2025-05-12 Remove AVR GPIO input / output macros, which are not directly applicable for CH559 ports configuration (defined by triple bPn_OC, Pn_DIR, Pn_PU registers).
    PS/2 mouse: Replace unnecessary PS/2 gohi / golo functions with direct pin SFR value assignment: PS/2 pins use PIN_MODE_OUTPUT_OPEN_DRAIN mode:
    high-impedance input weak standard bi-directional mode with open drain output, pins without pull-up resistor (external pull-ups used).
    PS/2 keyboard: remove unnecessary port mode change.
    Use Activity LED as SFR.
    [ps2_mouse.c]
2025-05-12 Set CH446Q delays to 4 us: 11 us measured clock period, 12 ms to full 128 switches reset.
    [CH446Q.c]
2025-05-12 Turn off Activity LED on PS/2 / USB keyboard / mouse key event.
2025-05-12 Remove BOOT1 switch from schematic. Correct LED polarity.
    [hidman_zx_bus.kicad_pcb, hidman_zx_bus.kicad_sch, zx.kicad_pcb]
2025-05-18 Fixed power on PS/2 mouse init issue with USB keyboard plugged in: INT1 delayed interrupt IE1 flag can be set while INT1 handler disabled, resulting in unwanted handler call immediately after INT1 in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
    Declare PS/2 mouse transmit / receive data packet variables as __data to speedup interrupt handler processing.
    Proper PS/2 mouse clock line release on port init.
    PS/2 mouse write: release clock line just before interrupt enable.
    [ps2_mouse.c]
2025-05-19 Implement mouse x/y axis scale by 1/2/3 factor: press F1/F2/F3 keyboard keys.
2025-05-19 Switch USB mouse from boot to report mode for mouse wheel support.
2025-05-23 HID gamepad / joystick support.
    Correct handling for HID values min/max range.
    ToDo: map values range only analog X/Y.
    Correct handling for more than one report in HID device report descriptor.
    32-bit HID values support omitted.
    8-bit Kempston joystick port implemented.
    Added joystick preset for mapping first 4 buttons and PoV Hat / D-Pad / X / Y axes to Kempston joystick port bits.
    Fist HID joystick mapped to Kempston joystick.
    Tested and working with:
    + DaemonBite Sega Controller To USB Adapter
    + Sony DualShock 4
    + Noname 2x DualShock to USB adapter
    - Sony DualShock 3 (not working, requires handshake implementation)
    [defs.h, main.c]
2025-06-02 Implement custom handlers for gamepads: - Sony DualShock 3 - XBox 360 USB Controller - XBox One Controller
    Custom handlers does not support gamepad to keyboad mapping.
    XBox One Controller driver not tested.
    TransferSend function not tested.
2025-06-02 Added global time_ms_32 timer counter.
    Enable PS/2 keyboard 250 ms bit receive timeout.
    Replace PS/2 mouse external init timeout counter to time_ms_32 read.
    [main.c, ps2_mouse.c]
2025-06-05 Replace 1812 polyfuse Littelfuse 1812L050PR (0.5A, 15V) with 1206 Bourns MF-NSMF075-2 (0.75A, 6V). Add schematic comments about CH559L omitted reset and external clock components.
    [hidman_zx_bus.kicad_pcb, hidman_zx_bus.kicad_sch]
2025-06-28 Prototype board: Fixed Help screen with Gluk Reset Service after power on. Add 10K pulldown resistor for STB signal, init P1 value before setting port to output.
    Fix not required for ZX BUS / CPLD implementation because of rising_edge of STB signal used instead of active high level.
    [zx.kicad_pcb, zx.kicad_sch]
2025-07-04 Assign CPLD pins according to PCB schematic.
2025-07-06 Changes based on assembled board tests: Set keyboard matrix registers values inverted (0 for pressed key). Output PAUSE, MAGIC, RESET as 1/0, active high: connected to external N-channel FET's gate. 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
    Update testbench according to changes.
    Update project description.
2025-07-10 Enable set Kempston Joystick port set initial value on power on reset.
2025-08-26 Fixed IP4220CZ6 ESD protection IC DM_B/DP_B connections.
    [hidman_zx_bus.kicad_pcb, hidman_zx_bus.kicad_sch]
2025-08-26 Switch to internal oscillator by default.
2025-08-28 Correct LED polarity on ZX BUS PCB.
    [hidman_zx_bus.kicad_pcb]
2025-08-28 Update ZX BUS PCB version to 1.1.
    [hidman_zx_bus.kicad_pcb]
2025-10-03 Experimental SEGA Mega Drive / Genesis 3-button gamepad support. D-pad, B,A,C buttons, START button translated to Kempston gamepad, button B as primary button.
    P2.3 are Sega Mega Drive / Genesis controller SELECT pin (open collector with pullup).
    P4 pins 0,1,2,3,4,5 are Sega Mega Drive / Genesis controller data input, open collector with pullups.
    Note: P4 supports pure input and push-pull output modes only.
    [zx.kicad_sch]
2025-10-07 Xbox One / Series S/X controllers support. Tested with Xbox One Controller Model 1537, Xbox Series S/X Controller Model 1914.
    Expect controller to be in blinking LED state on power on / connect to be detected as USB device.
    ToDo: Match behavior with Windows PC, expected init controller in any state.
    Rumble on connect / rumble support not working.
    Supported devices (USB VID/PID):
    {0x045E, 0x02D1} Microsoft X-Box One pad
    {0x045E, 0x02DD} Microsoft X-Box One pad (Firmware 2015)
    {0x045E, 0x02E3} Microsoft X-Box One Elite pad
    {0x045E, 0x02EA} Microsoft X-Box One S pad
    {0x045E, 0x0B00} Microsoft X-Box One Elite 2 pad
    {0x045E, 0x0B0A} Microsoft X-Box One Adaptive Controller
    {0x045E, 0x0B12} Micro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
    [xbox_one.c]
2025-10-10 Add "GameSir G7 SE" controller ID to Xbox One driver.
2026-10-25 Implement mouse pointer control with DualShock 4 / DualSense touchpad. Touchpad second touch mapped to mouse left button, touchpad click mapped to mouse right button. Also DualShock 4 / DualSense con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
    Shared mouse state updated only when touch movement or mapped buttons state changes detected.
    User custom device handlers moved out from usbhost.c.
    Extracted global shared unsafe buffer g_shared_packed_buffer[64] for reading device reports (note: duplicates ReceiveDataBuffer[512] in usbhost.c).
    ps3_usb_init: extract only one input endpoint.
    Note: introduced shared global states for DualShock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
2026-10-25 Map DualShock 3 left stick as mouse pointer, L1/R1 as left/right mouse buttons.
